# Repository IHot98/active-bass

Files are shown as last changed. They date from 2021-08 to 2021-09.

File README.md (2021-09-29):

# Aktivna bass gitara s ugrađenim zvučnikom

Dizajn tiskane pločice napravljem pomoću KiCad-a.

Tiskana pločica dizajnirana je kao jednoslojna pločica radi lakšeg procesa jetkanja, a komponente su dijelom THT i SMD jer u trenutku izrade nije bilo pristupa drugačijim.

## Slike

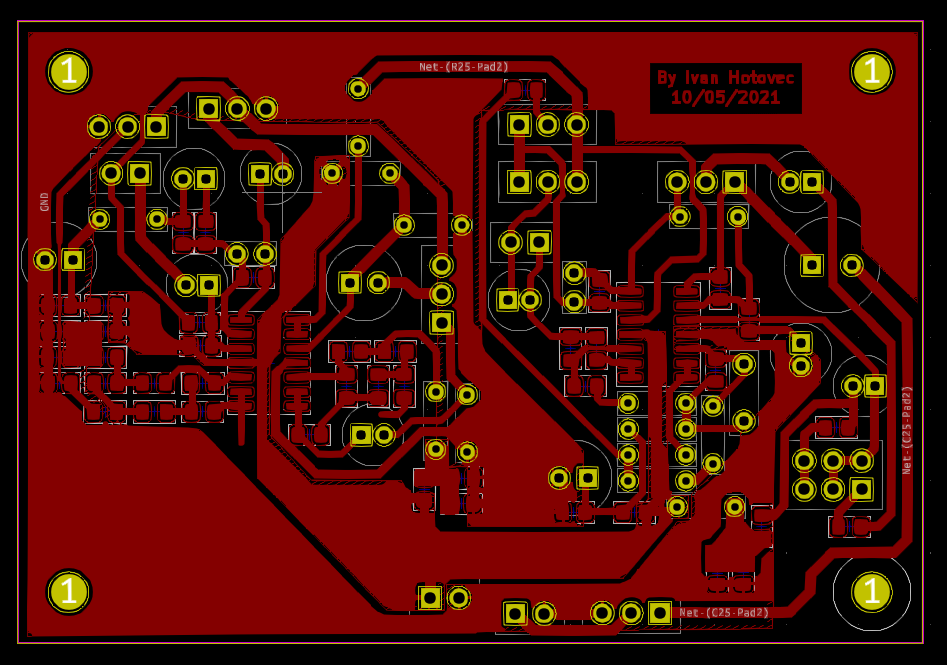
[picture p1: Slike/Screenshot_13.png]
Layer 1


Prikaz dizajna pločice

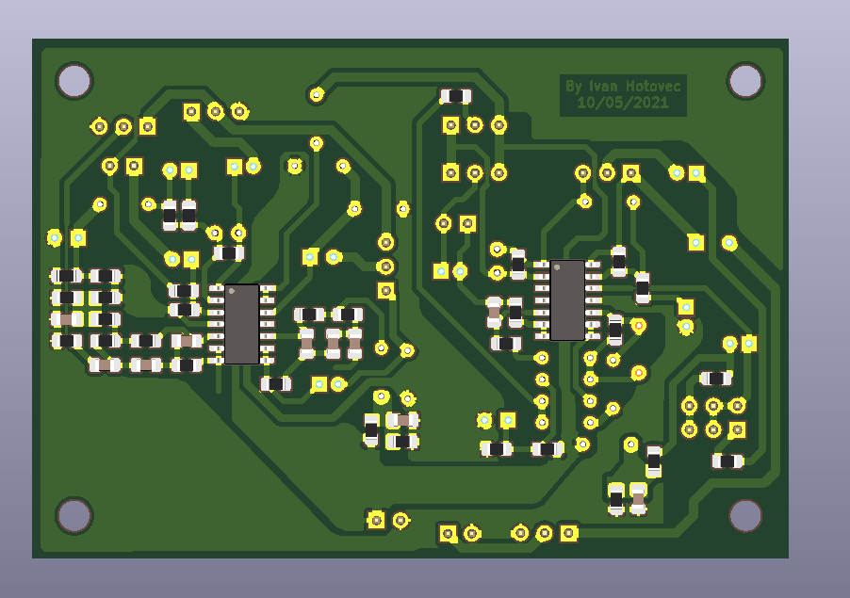
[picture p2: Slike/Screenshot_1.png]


3D Prikaz

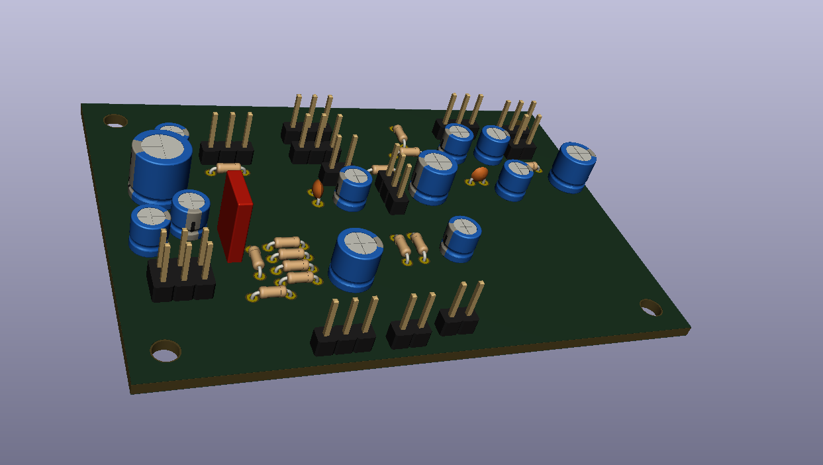
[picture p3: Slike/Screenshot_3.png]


3D Prikaz

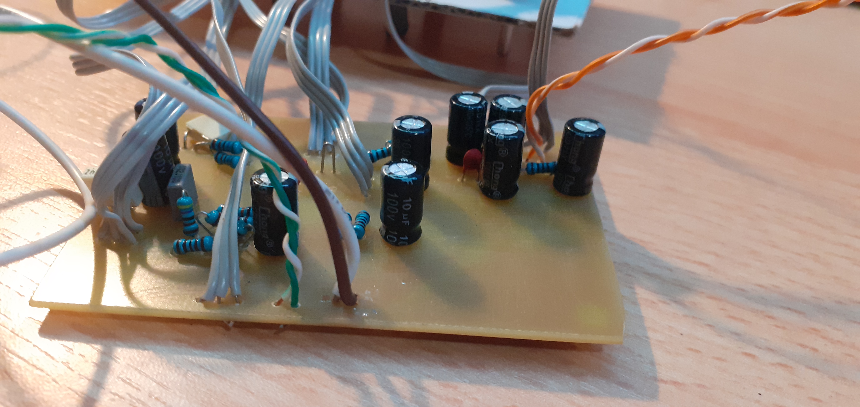
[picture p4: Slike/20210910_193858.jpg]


Izrađeni sklop

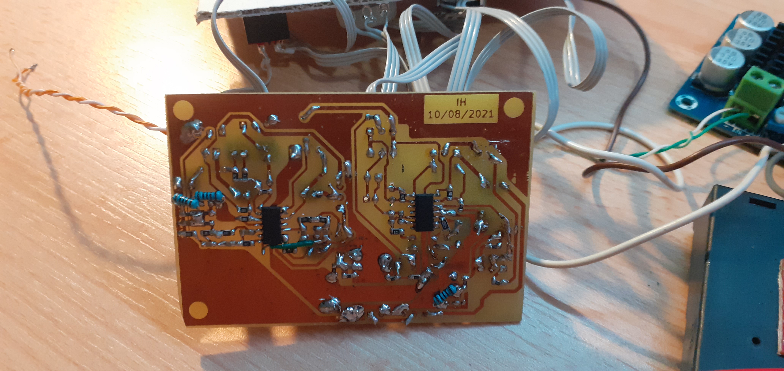
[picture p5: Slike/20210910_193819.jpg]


Izrađeni sklop

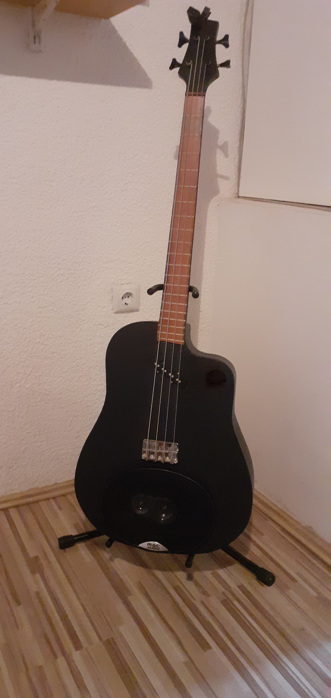
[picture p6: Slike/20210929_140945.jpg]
Kompletirani projekt


Kompletirana bass gitara

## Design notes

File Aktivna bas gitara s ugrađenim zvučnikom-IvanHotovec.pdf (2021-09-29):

SVEUČILIŠTE JOSIPA JURJA STROSSMAYERA U OSIJEKU

FAKULTET ELEKTROTEHNIKE, RAČUNARSTVA I

INFORMACIJSKIH TEHNOLOGIJA

Sveučilišni studij

## AKTIVNA BAS GITARA S UGRAĐENIM ZVUČNIKOM

Završni rad

## Ivan Hotovec

Osijek, 2021.

SADRŽAJ

### 1. UVOD

Prilikom svatovskih pratnji ili sličnih glazbenih nastupa gdje je potrebno biti u pokretu, najčešće

se koristi berda ili kontrabas u sklopu glazbenog sastava. Ti su instrumenti jako veliki, teški i

nezgrapni za nositi te glazbeniku predstavljaju problem u tim situacijama. Ovaj se rad temelji na

rješavanju problema s dizajniranjem i izradom instrumenta koji je manji, lakši za nositi i bez

utjecaja na glasnoću i kvalitetu zvuka.

Problem veličine i mase instrumenta rješava se na način da se tradicionalno bas pojačalo i zvučnik

integriraju u sami instrument te da se napravi takozvani „all-in-one“ instrument.

U radu će se obratiti pozornost na dizajniranje predpojačala, odabir adekvatnog pojačala snage i

sustav baterija kojim će se svi sklopovi napajati.

### 1.1. Zadatak završnog rada

Zadatak završnog rada je izrada i testiranje aktivne bas gitare s ugrađenim zvučnikom.

### 2. PRIKAZ CIJELOG SUSTAVA

Slika 2.1 prikazuje blokovsku shemu cijelog sustava sa svim podsustavima korištenim u ovome

radu.

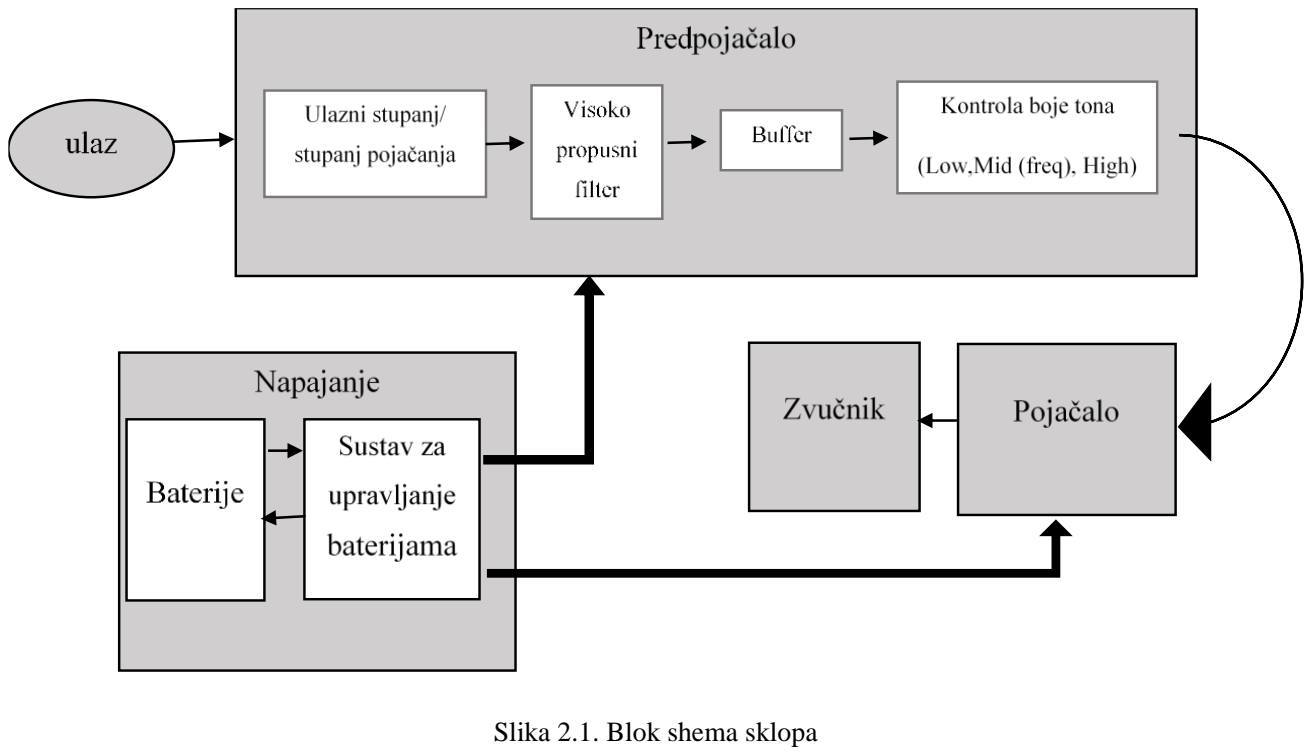
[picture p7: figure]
Slika 2.1. Blok shema sklopa

### 3. PREDPOJAČALO

### 3.1. Ulazni stupanj

Ulazni stupanj izveden je pomoću jednog operacijskog pojačala u neinvertirajućem spoju, a

regulacija pojačanja odvija se pomoću potenciometra spojenog na izlaz operacijskog pojačala.

Korišteno je operacijsko pojačalo TL074. Bitne karakteristike TL074 pojačala su niski šum i

visoka ulazna impedancija zato što koristi JFET-ove kao ulazni stupanj. Ulazni stupanj služi za

naponsko pojačanje za pojačalo, a budući da ima veliki ulazni otpor, na njega se može spojiti

većina izvora signala s visokom ili niskom izlaznom impedancijom. Ulazni stupanj izveden je

pomoću operacijskih pojačala jer je jednostavnije, jeftinije i pouzdanije od izvedbe s diskretnim

tranzistorima.

U dolje navedenoj shemi (Slika 3.1.) kondenzatori C1 i C5 služe za filtriranje DC komponente

signala, a otpornik R7 je u negativnoj povratnoj vezi te s otpornicima R3, R8, određuju pojačanje

ovoga stupnja. Naponsko pojačanje ovoga stupnja može se izračunati po formuli:

Av = 1 + (

R2
R1
) | (3.1.)

Kada se uvrste komponente ovoga sklopa u formulu dobije se formula:

Av = 1 + (

R7
R3 ∗ R8
R3 + R8

+ R6

)
(3.2.)

Av = 1 + (
10k
2.7k ∗ 1.8k
2.7k + 1.8k

+ 1k

) = 5.807 = 15.27dB | (3.3.)

Dizajnom ovoga sklopa dobiva se naponsko pojačanje od +15dB.

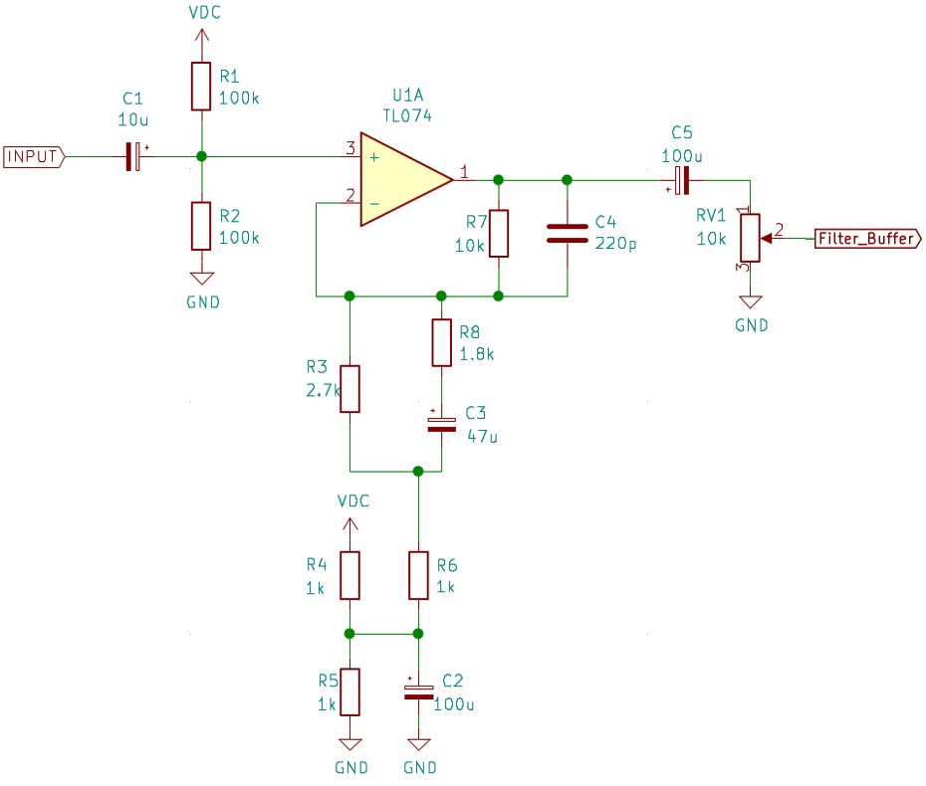
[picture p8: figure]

### 3.2. Kontrola boje tona

### 3.2.1. Bass i treble

Primarne kontrole boje tona kao i uvijek su bas i treble, odnosno kontrola niskih i visokih tonova.

Postoji mnogo različitih načina na koje se mogu provesti kontrole varijabilne frekvencije, ali ova

je metoda prilično jednostavna i dovoljno dobro funkcionira za potrebe ovoga sklopa. Kontrola

boje niskih i visokih tonova bazirana je na principu Wien-ovog mosta. Kontrola boje tona niskih i

visokih ima prilagodljivu frekvenciju pojačanja ili prigušenja. Niski tonovi mogu se regulirati od

100Hz do 500Hz, a visoki od 400Hz do 1.7kHz. Sklop omogućuje pojačanje (+12dB) i prigušenje

(-12dB) na obje kontrole tona. Kontrola niskih koristi giratorski baziranu zavojnicu, a kontrola

visokih koristi prilagodljiv multiplikator kapaciteta.

Slika 3.1. Shema ulaznog stupnja predpojačala

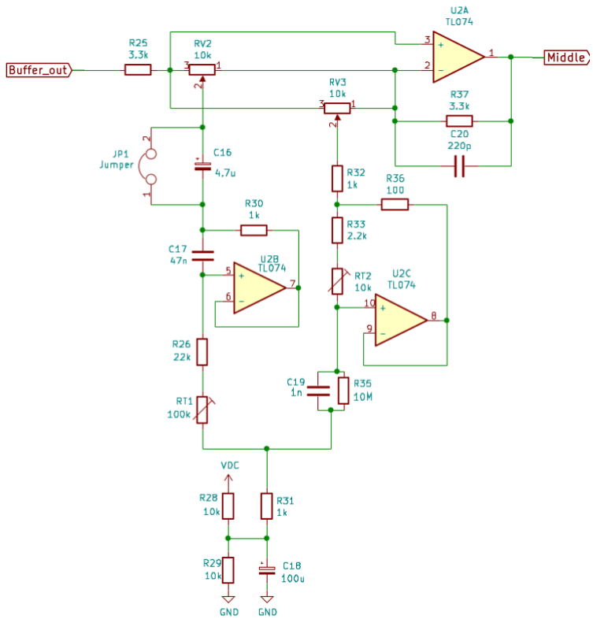
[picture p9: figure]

Slika. 3.2. Električna shema sklopa za kontrolu boje tona niskih i visokih frekvencija

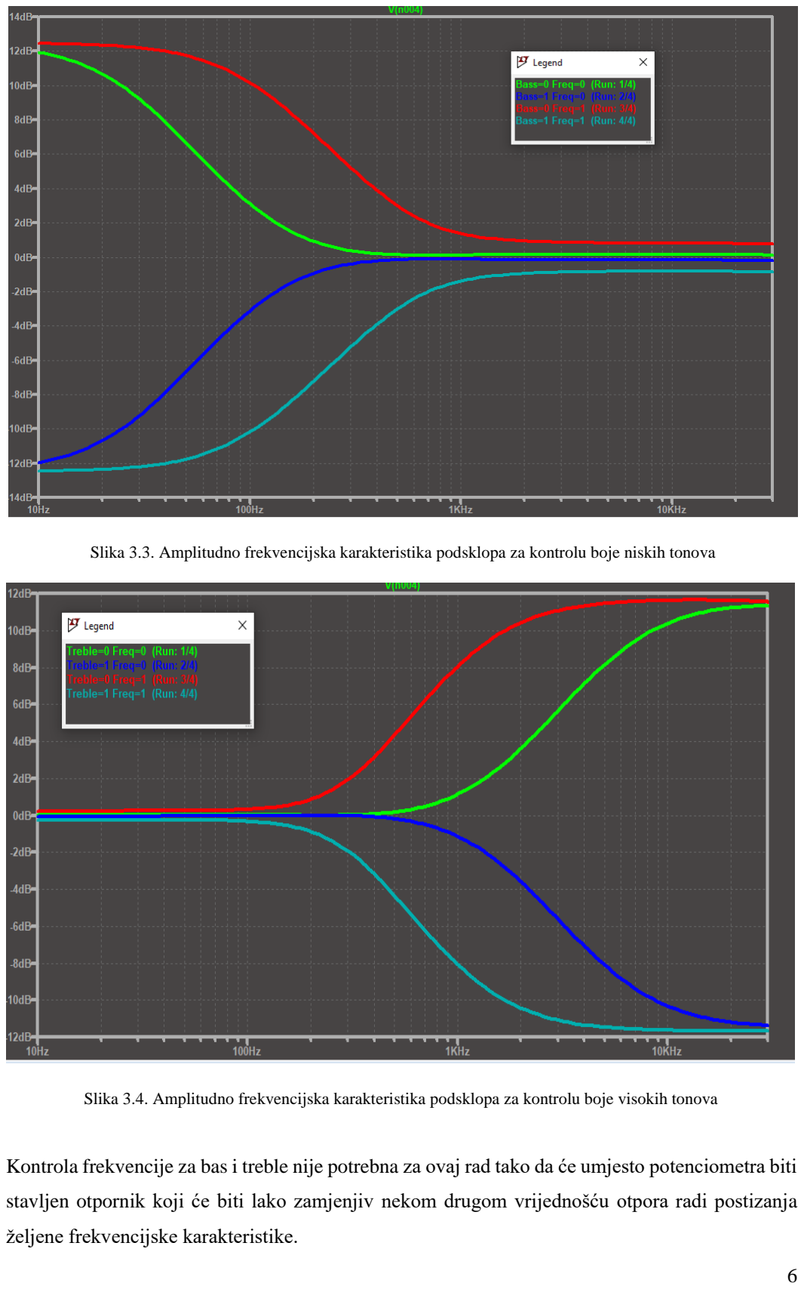
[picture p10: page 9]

Kontrola frekvencije za bas i treble nije potrebna za ovaj rad tako da će umjesto potenciometra biti

stavljen otpornik koji će biti lako zamjenjiv nekom drugom vrijednošću otpora radi postizanja

željene frekvencijske karakteristike.

Slika 3.3. Amplitudno frekvencijska karakteristika podsklopa za kontrolu boje niskih tonova

Slika 3.4. Amplitudno frekvencijska karakteristika podsklopa za kontrolu boje visokih tonova

### 3.2.2. Middle – kontrola boje srednjih tonova

Middle kontrola napravljena je tako da ima pojačanje i prigušenje od maksimalno 12dB. Spaja se

kaskadno poslije kontrole niskih i visokih tonova (basi treble). Frekvencija pojačanja ili prigušenja

može se prilagođavati duplim potenciometrom od 650Hz do 7.7kHz. Frekvencijsko se područje

može dodatno promijeniti tako da mijenjamo vrijednosti kondenzatora C21 i C23, ali treba

pripaziti da su kondenzatori jednakih vrijednosti. Koristeći formulu (3.4.) za RC frekvenciju može

se izračunati koje kondenzatore treba uzeti za određeni raspon frekvencija.

f =

1
2πRC

(3.4)

U ovome sklopu Q faktor ostaje konstantan kako se mijenja frekvencija, a zbog minimizacije šuma

u sklopu korišteni su otpori relativno niskih otpornosti.

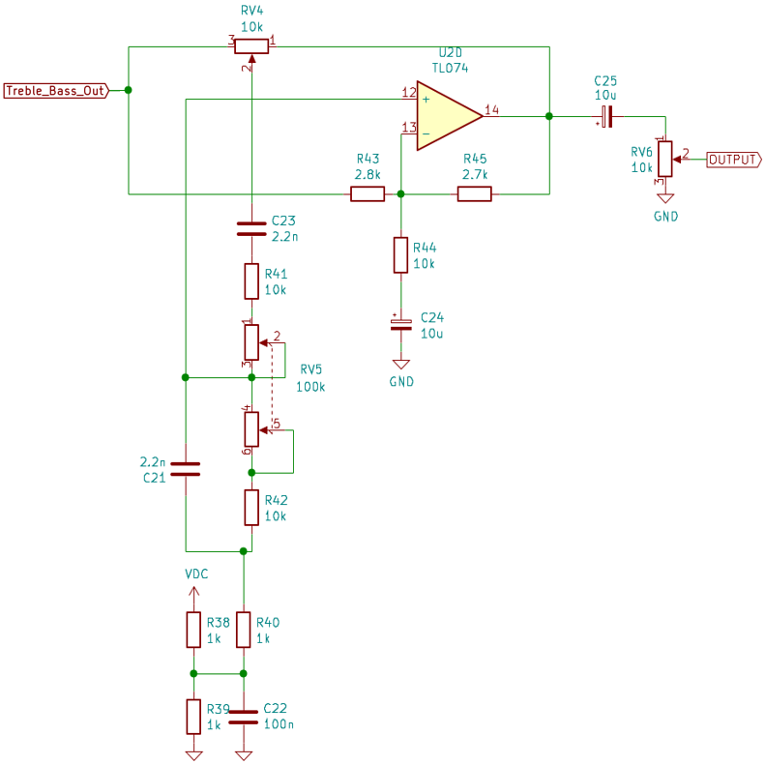
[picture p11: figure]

Slika 3.5. Električna shema sklopa za kontrolu boje srednjih tonova

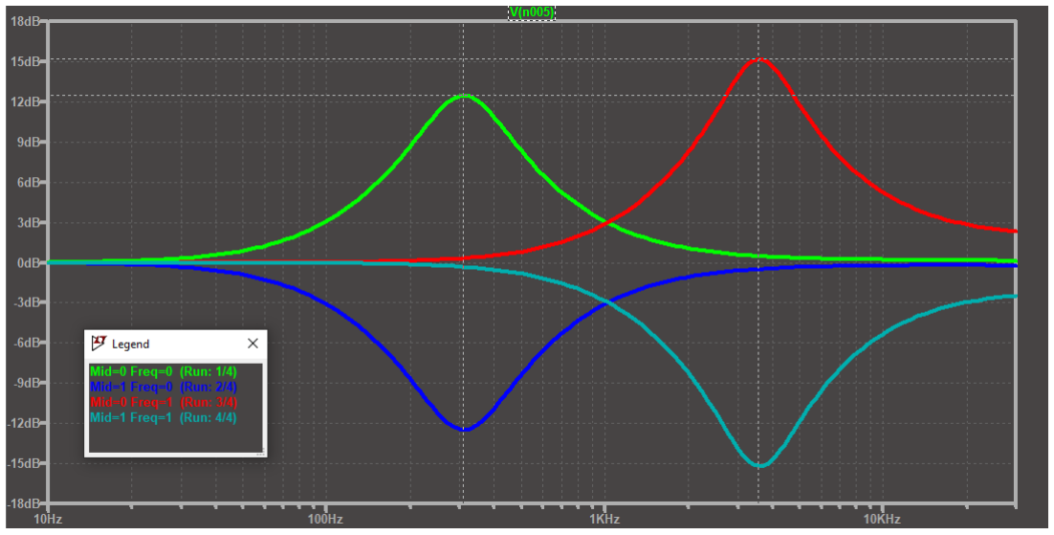
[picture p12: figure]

Na slikama 3.3, 3.4 i 3.6 možemo primijetiti prozor s natpisom legenda u kojemu različitim bojama

ima napisano Bass, Treble ili Mid i Freq te je izjednačeno s 1 ili 0. Navedeni natpisi predstavljaju

varijablu koja služi za određivanje položaja klizača na potenciometru u simulaciji. Nula

predstavlja da je klizač potenciometra na krajnjem minimalnom položaju, dok jedinica predstavlja

krajnji maksimalni položaj. Vrijednost varijable položaja klizača može biti bilo koji realni broj od

0 do 1, ali radi preglednosti grafova u simulaciji uzeti su samo krajnji položaji klizača. Varijable

označene s Bass, Treble i Mid utječu na pojačanje i prigušenje toga dijela sklopa, a varijabla Freq

utječe na frekvenciju gdje će to pojačanje ili prigušenje biti.

### 3.2.1. Wien-ov most

Wien-ov most srce je gotovo svih audio oscilatora (Slika 3.7.). U oscilatoru, krug pojačanja se

koristi za dobivanje pozitivne povratne veze oko wien-ovog mosta, a negativna povratna veza

zahtijeva stabilizaciju pojačanja kako bi se dobilo pojačanje od 3, što je dovoljno za održavanje

oscilacije. Kada se wien-ov most kombinira s povratnom vezom, Q faktor je uvelike poboljšan, a

gubitak snage više nije problem. Pod uvjetom da je pojačanje sklopa ispod 3, wien-ov most neće

iznenada postati oscilator, a u sklopu prikazanom na slici 3.8. će pružiti +/- 9dB pojačanja i

prigušenja, pod kontrolom potenciometra. Kako bi sklop bio korisniji, sklop mora imati i

mogućnost mijenjanja frekvencije. To se postiže pomoću dvostrukog potenciometra tako da se oba

otporna dijela mosta mogu mijenjati. Frekvencija se može podesiti u rasponu od jedne dekade, što

je nešto više od tri oktave. Ako je potrebno više pojačanja i prigušenja (i malo veći Q), može se

staviti C1 dvostruko veći od C2 (ili dodati R5 – slika 3.8.). Promjenom C1 znači da će se

Slika 3.6. Amplitudno frekvencijska karakteristika sklopa za kontrolu boje srednjih tonova frekvencija također promijeniti, a kako bismo mogli izračunati frekvenciju možemo koristiti

formulu (3.5.).

f =

0.717
2πRC

(3.5.)

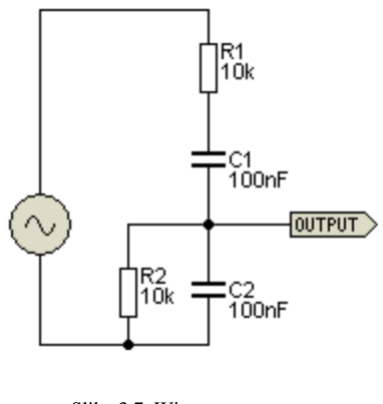
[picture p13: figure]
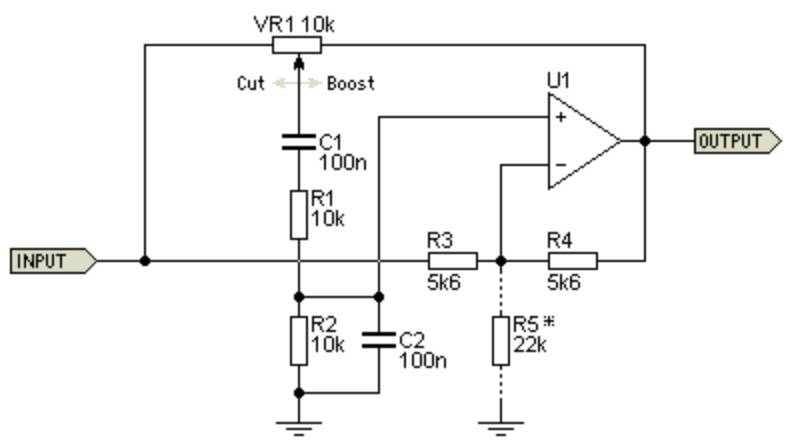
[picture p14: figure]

### 3.2.2. Giratorski filter

Giratori ili simulirane zavojnice neizmjerno su korisni elektronički građevni blokovi. U

jednostavnim terminima, girator je aktivni pretvornik impedancije. Korištenjem kondenzatora kao

reaktivne komponente, girator pretvara impedanciju s kapacitivne na induktivnu. Umjesto

korištenja zavojnice koja je namotana oko magnetske jezgre, aktivni uređaj, najčešće operacijsko

pojačalo, koristi se kao pretvornik impedancije. Na taj se način kondenzator može koristiti kao

Slika 3.7. Wien-ov most

Slika 3.8. Wien-ov most u shemi s operacijskim pojačalom kontrolni element, a operacijsko pojačalo transformira njegovu impedanciju tako da se cijeli krug

ponaša kao zavojnica. U stvarnosti, zavojnica će imati značajnu otpornost namota i jer je to namot

žice s feromagnetnom jezgrom, jezgra će pokupiti zračenja magnetskog polja. Osim toga, postoji

i kapacitet unutar namota, što znači da će imati samo rezonantnu frekvenciju koja može biti čak i

unutar audio spektra. Usporedbom, zavojnica ostvarena s operacijskim pojačalom i nekoliko

pasivnih komponenata gotovo da neće imati samostalnog kapaciteta i može biti dizajnirana tako

da ima iznimno nizak otpor namota. Također nema ničega što bi moglo pokupiti zalutala

magnetska polja, pa postavljanje na tiskanoj pločici nije kritično. Giratori se ne moraju nositi s

gubicima jezgre i osjetljivosti na magnetska polja. S obzirom na to da je jeftin, a može se

podešavati i štedi na prostoru, čini se kao vrlo dobar izbor za korištenje u sklopovima za kontrolu

boje tona.

3.3. 40 Hz visoko propusni filter

Visoko-propusni filter izveden je poput uobičajenog Sallen-Key filtera, ali uz neka

pojednostavljenja kako bi se smanjio broj različitih vrijednosti komponenata. Q faktor ili faktor

dobrote optimiziran je na način da omogućuje veću ulaznu impedanciju nego što bi inače bilo

moguće, s tim da je konačni Q ta dva filtera spojenih kaskadno iznosi točno 0.707, nema pojačanja

na donjoj graničnoj frekvenciji, poput tradicionalnog butterworth-ovog filtera

Sklop filtera može se zaobići korištenjem DPDT prekidača kao što je vidljivo na shemi te isti

omogućuje da filter bude uključen kada postoji potreba za uklanjanjem neželjenih niskih

frekvencija.

Kako ne bi dolazilo do pucketanja zvuka pri uklapanju i isklapanju sklopke, postavljeni su

otpornici R9 i R22 i kondenzator C14. Pucketanje u zvuku obično se dešava kada postoji razlika

u potencijalu između kontakata prekidača ili ako postoji kondenzator kojemu će jedan izvod biti

„u zraku“ što ovi otpornici i kondenzator sprječavaju.

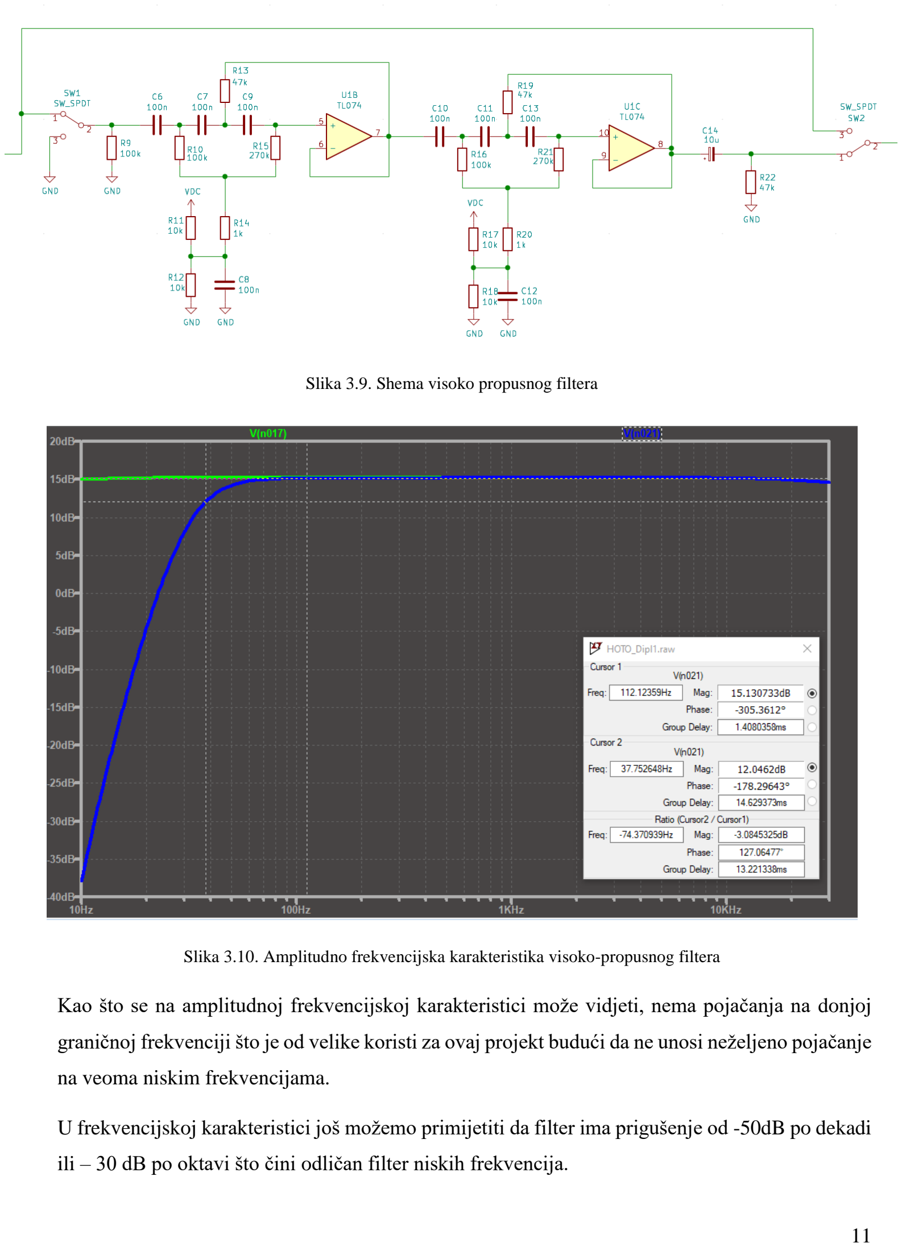
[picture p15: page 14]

Kao što se na amplitudnoj frekvencijskoj karakteristici može vidjeti, nema pojačanja na donjoj

graničnoj frekvenciji što je od velike koristi za ovaj projekt budući da ne unosi neželjeno pojačanje

na veoma niskim frekvencijama.

U frekvencijskoj karakteristici još možemo primijetiti da filter ima prigušenje od -50dB po dekadi

ili – 30 dB po oktavi što čini odličan filter niskih frekvencija.

Slika 3.9. Shema visoko propusnog filtera

Slika 3.10. Amplitudno frekvencijska karakteristika visoko-propusnog filtera

Frekvencija reza prilagođena je na 40hz specifično zbog toga što najniži ton na bas gitari iznosi

41 Hz, te kako ne bismo prigušavali „korisne“ tonove rez filtera mora biti manji od najnižega tona

što instrument može reproducirati.

### 3.4. Postavljanje radne točke

Kako u ovome dizajnu koristimo operacijska pojačala, a za rad operacijskog pojačala potreban je

i pozitivan i negativan napon, a budući da se sklop napaja pomoću baterija, nije moguće dobiti

dualni (+/-) napon na kojima OP može raditi nego je potrebno napraviti stabilnu referentnu točku

na pola napona što nam je omogućeno od baterija. To postižemo sklopom na slici 3.11. gdje R4 i

R5 služe kao naponsko dijelilo, a R6 i C2 kao filter radi stabilnosti referentne točke i neovisnost

od napajanog dijela sklopa.

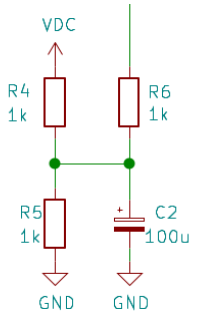
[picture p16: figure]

Kod odabira otpornika za ovaj sklop potrebno je imati na umu otpornost tereta tj. otpornici R4 i

R5 moraju biti deset puta manji nego otpor tereta te kolika struja prolazi kroz te otpore kako bi se

mogli odabrati dovoljno snažni otpornici.

Slika 3.11. Sklop za postavljanje radne točke

### 3.5. Izrada tiskane pločice

### 3.5.1. Dizajn tiskane pločice

Dizajn tiskane pločice napravljen je u KiCad programskom sučelju koji je brz i jednostavan za

korištenje pri izradi manjih i jednostavnijih tiskanih pločica. Tiskana pločica dizajnirana je kao

jednoslojna pločica s kombinacijom SMD i THT komponenata radi lakšeg razvijanja pločice.

Na slici 3.12. može se vidjeti gotov dizajn tiskane pločice.

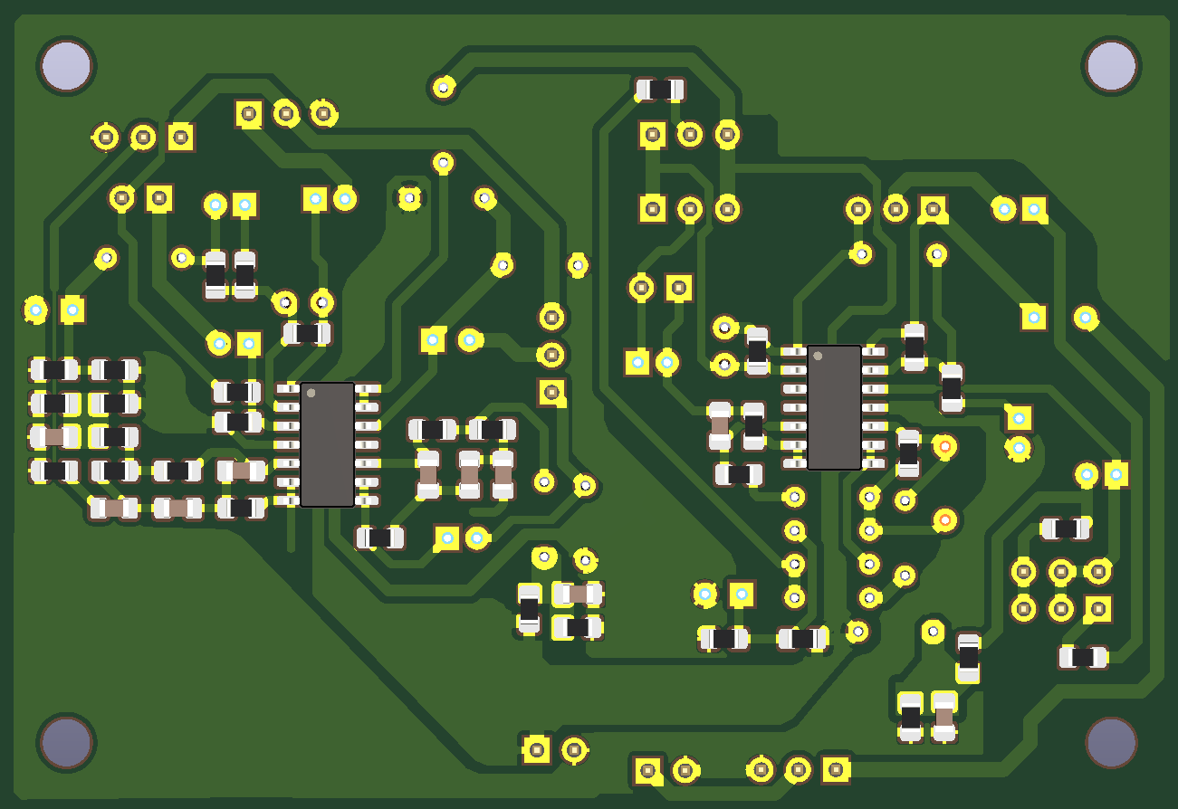
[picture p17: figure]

### 3.5.2. Jetkanje tiskane pločice

Za razvijanje pločice korišten je foto postupak gdje se dizajn pločice ispiše na paus papir s

laserskim printerom. Za foto postupak trebaju posebne pločice s tankim slojem fotorezista, sloj

koji kada se izloži svjetlosti gubi otpornost na otapala, te se paus papir prisloni na bakrenu stranu

pločice i zatim osvijetli s UV svjetlom. Nakon osvjetljivanja pločicu stavimo u otopinu natrijevog

hidroksida gdje se odstrani fotorezist, zatim stavimo pločicu u otopinu solne kiseline i vodikovog

peroksida gdje se nagriza bakar. Nakon nagrizanja bakra na tiskanoj pločici izbuše se rupe za

komponente s žičanim izvodima. Tiskane pločice su izrađene u kombinaciji tehnologije površinske

Slika 3.12. Tiskana pločica montaže (SMD) i komponentama s žičanim izvodima (Trough-hole). Bitne prednosti tehnologije

površinske montaže komponenata su minijaturizacija tj. ušteda na prostoru i masi, bolje električke

karakteristike, bolje mehaničke karakteristike, odnosno veća izdržljivost na udarce i vibracije.

Jedini nedostatci tehnologije površinske montaže su složeniji tehnološki postupci lemljenja, teže

ispitivanje zbog slabije pristupačnosti priključcima na komponenti i nedostupnost nekih

komponenti u SMD-u.

### 3.6. Testiranje

Nakon izrade tiskane pločice i lemljenja svih komponenti, potrebno je provjeriti ispravnost/točnost

izrade. To se postiže testiranjem koje se odvija pomoću ARTA softvera i zvučne kartice gdje se

promatra frekvencijski odaziv sklopa.

Kako bi se dobili točni rezultati, potrebno je kalibrirati zvučnu karticu programom. To se čini

postupkom opisanom u korisničkom priručniku koji se može naći na službenoj web stranici.

Kako bi se zvučna kartica zaštitila od višeg napona nego što je to predviđeno, potrebno je prigušiti

signal. To se radi dodavanjem sklopa prije ulaza u zvučnu karticu kao što je na slici 3.13.

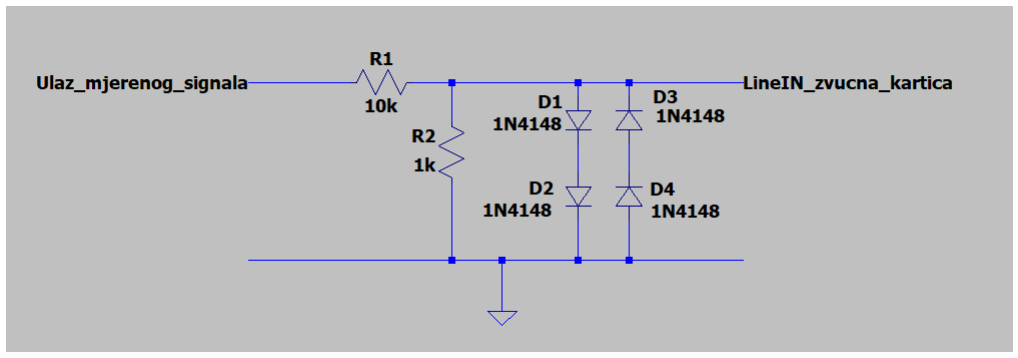
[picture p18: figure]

Slika 3.13. sklop za prigušenje signala

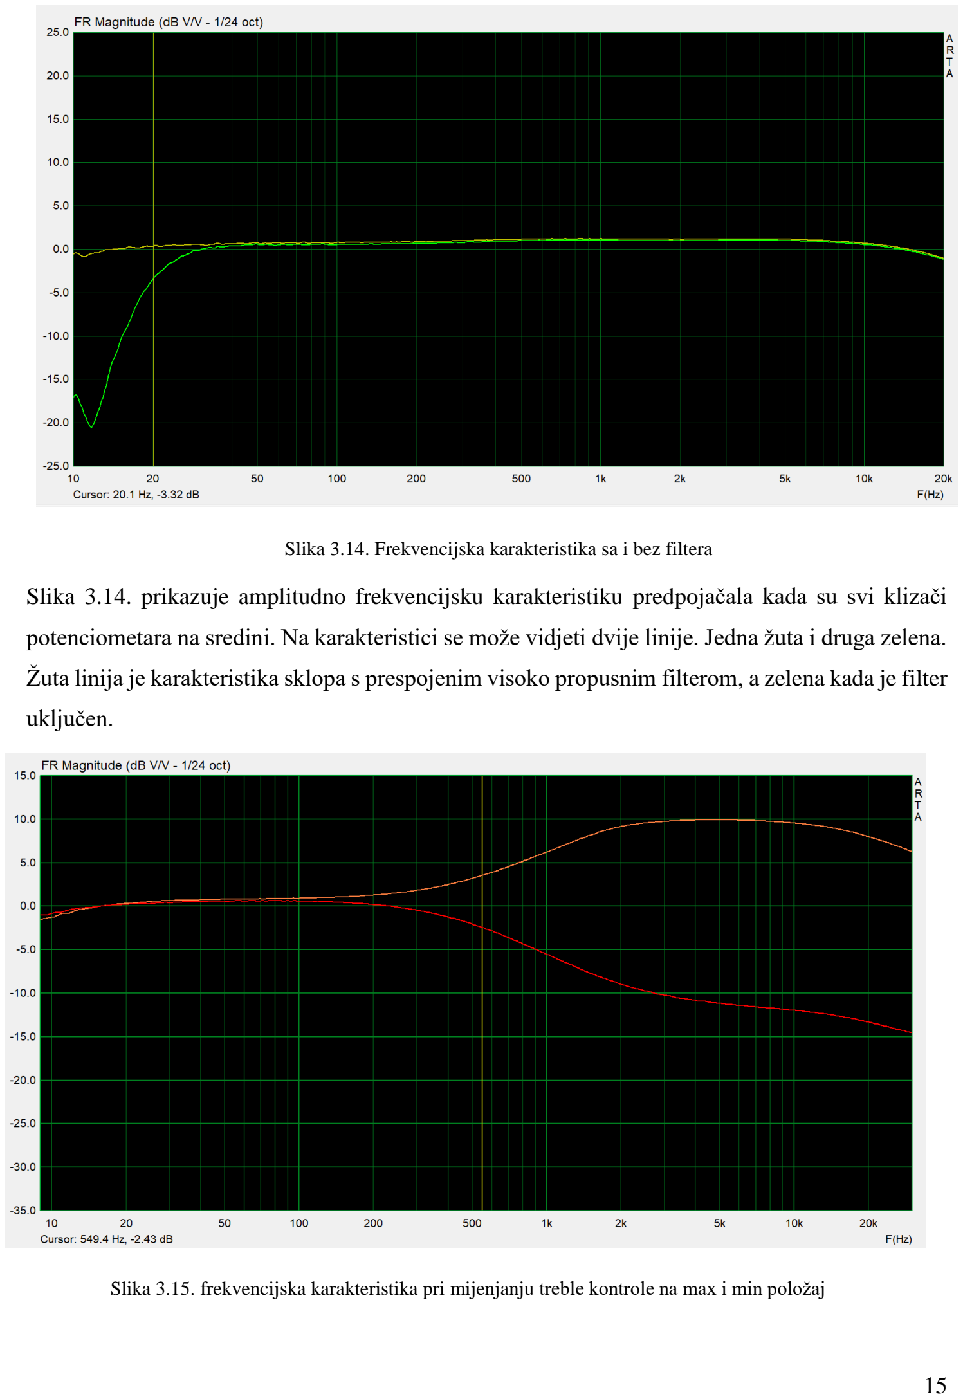
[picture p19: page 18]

Slika 3.14. prikazuje amplitudno frekvencijsku karakteristiku predpojačala kada su svi klizači

potenciometara na sredini. Na karakteristici se može vidjeti dvije linije. Jedna žuta i druga zelena. Žuta linija je karakteristika sklopa s prespojenim visoko propusnim filterom, a zelena kada je filter

uključen.

Slika 3.14. Frekvencijska karakteristika sa i bez filtera

Slika 3.15. frekvencijska karakteristika pri mijenjanju treble kontrole na max i min položaj

Slika 3.15 prikazuje amplitudno frekvencijsku karakteristiku kada su svi klizači potenciometara

na sredini osim potenciometra za kontrolu visokih tonova (Treble). Crvenom je linijom prikazana

karakteristika kada je klizač Treble potenciometra na minimumu (potpuno zarotiran u lijevo), a

narančastom kada je klizač na maksimumu (potpuno zarotiran u desno).

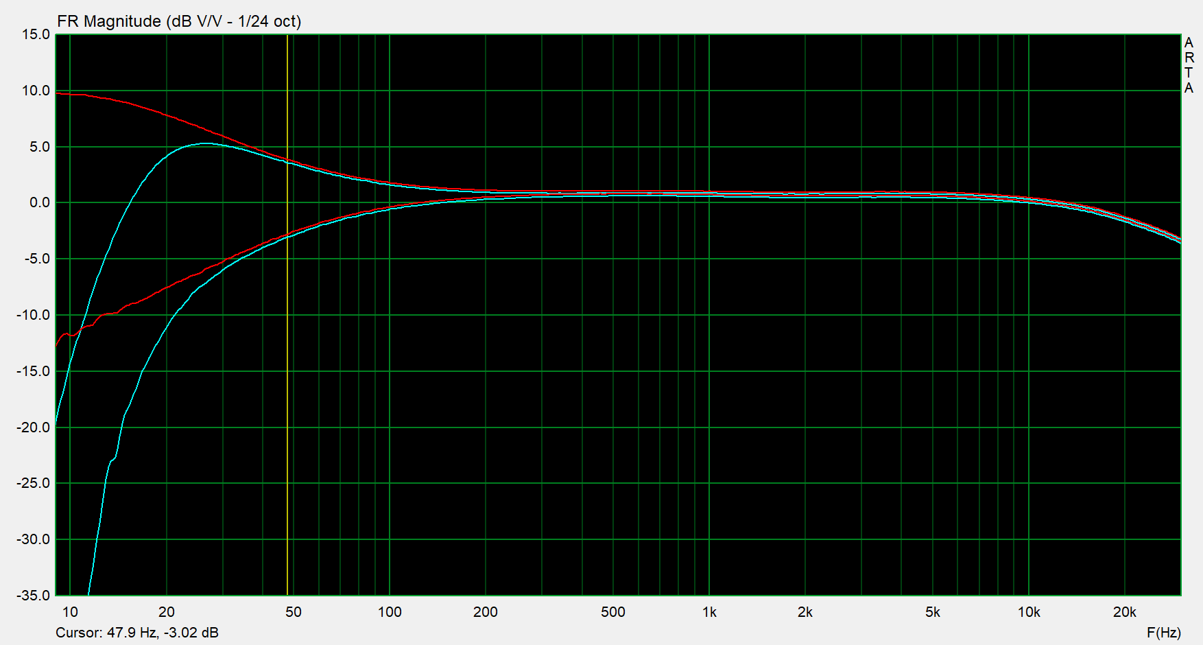
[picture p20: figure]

Slika 3.16 prikazuje amplitudno frekvencijsku karakteristiku kada su svi klizači potenciometara

na sredini osim potenciometra za kontrolu niskih tonova (Bass). Crvenom je linijom prikazana

karakteristika bez uključenog visoko-propusnog filtera, a plava s uključenim visoko propusnim

filterom.

Slika 3.16. frekvencijski odaziv bass kontrole tona s i bez filtera

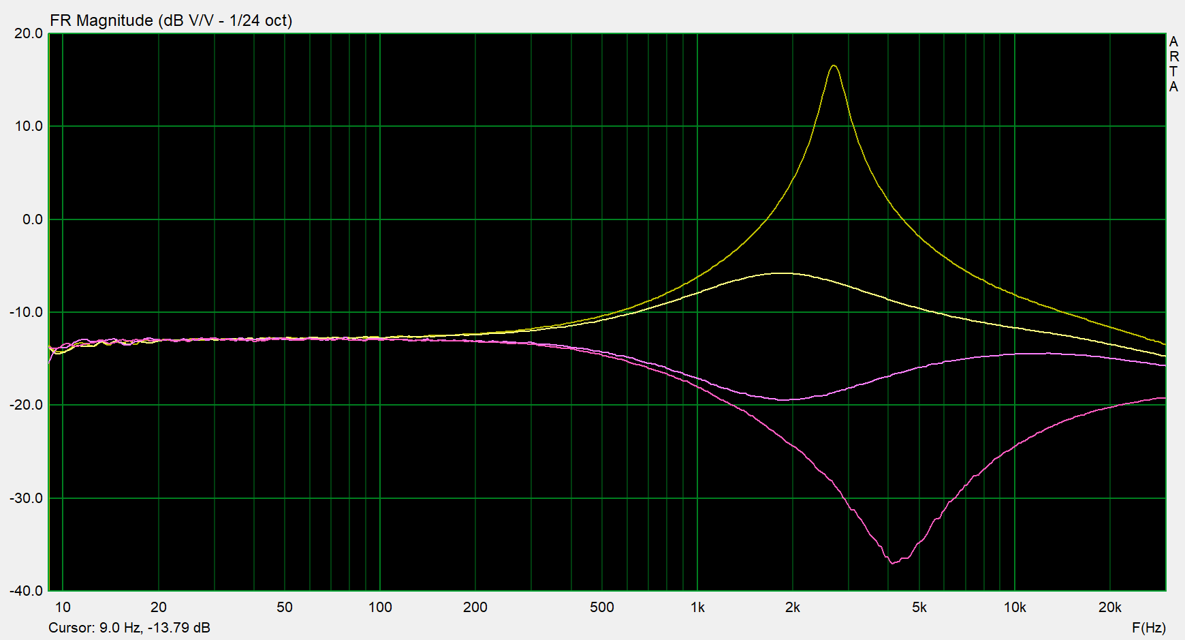
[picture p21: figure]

Slika 3.17 prikazuje amplitudno frekvencijsku karakteristiku kada su svi klizači potenciometara

na sredini osim potenciometra za kontrolu srednjih tonova (Mid) i potenciometra za kontrolu

frekvencije. Svijetlo-žutom linijom prikazana je karakteristika kada je Mid potenciometar

zarotiran krajnje u desno i kada je potenciometar za frekvenciju zarotiran krajnje u lijevo. Tamno-

žutom linijom prikazana je karakteristika kada je Mid potenciometar zarotiran u potpunosti u

desno i kada je potenciometar za frekvenciju zarotiran u potpunosti u desno. Ljubičastom linijom

je prikazana karakteristika kada je Mid potenciometar zarotiran u potpunosti u lijevo i kada je

potenciometar za frekvenciju zarotiran skroz u lijevo. Ružičastom linijom prikazana je

karakteristika kada je Mid potenciometar zarotiran u potpunosti u lijevo i kada je potenciometar

za frekvenciju zarotiran u potpunosti u desno.

Mjerenje se izvršilo na način da se na izlaz zvučne kartice puštao sinusoidni signal od 10 Hz do

50kHz pri frekvenciji uzorkovanja od 192kHz te se na ulaz zvučne kartice spojio izlaz sklopa i

mjerila se amplituda sinusa na svakoj frekvenciji.

Slika 3.17. Frekvencijski odaziv kontrole srednjih tonova

### 4. POJAČALO

### 4.1. Odabir klase pojačala

Postoji više klasa audio pojačala i svake od njih imaju svoje dobre i loše strane. Za potrebe ovoga

rada pojačalo treba biti što efikasnije i što manje mase te je potrebno da samo pojačalo može raditi

s jednom naponskom razinom tj. da pojačalo može raditi s jednostrukim napajanjem („single

rail“) odnosno direktno sa baterija. Kada uzmemo u obzir ove kriterije jedino D klasa pojačala

zadovoljava sve uvjete. Točnije čip pojačalo TPA3116D2 u PBTL (eng. Parallel Bridge Tied

Load) modu, odnosno dva kanala spojeno u paralelni mostni spoj.

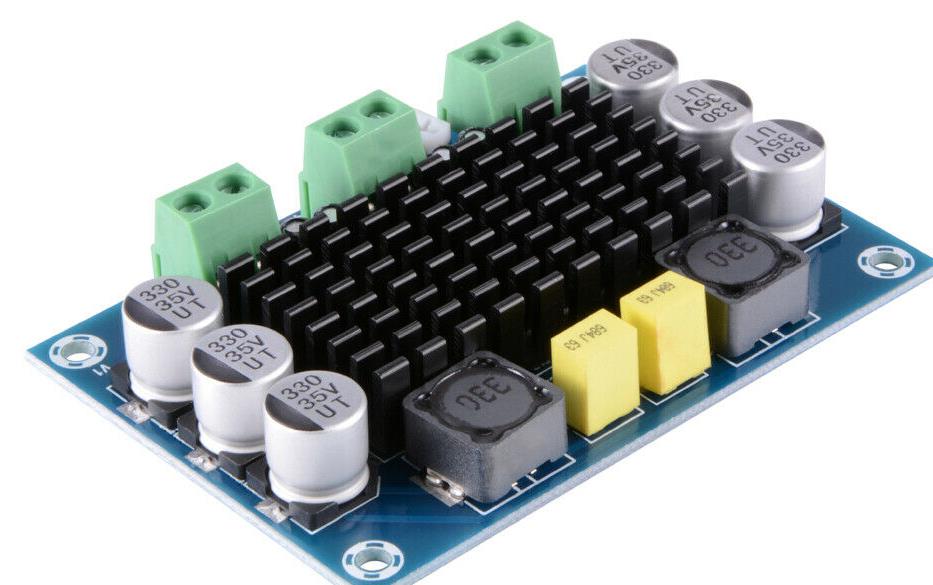
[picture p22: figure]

### 4.2. Specifikacije pojačala

Izabrano pojačalo radi na naponima od 12 do 26V, te na naponu od 24V može podnijeti

maksimalnu snagu od 100W što je i više nego dovoljno za naše potrebe. Nadalje pojačalo ima

visoki SNR (100dB) što omogućava iznimnu kvalitetu zvuka. Samo pojačalo ima vrlo male

dimenzije (79x54x16mm) i masu (54g).

Čip TPA3316D2 pruža sveobuhvatnu zaštitu od kratkog spoja, prekomjerne temperature,

prenapona, pod napona i istosmjernih smetnji i preopterećenja.

Slika 4.1. TPA3116D2 pojačalo

### 5. BATERIJE / BMS

### 5.1. Odabir baterija

Postoje različite vrste baterija napravljene od različitih materijala, a bitna karakteristika za ovaj

rad je da su baterije punjive, da zauzimaju malo prostora, te da su lagane. Neke od poznatijih vrsta

baterija su olovna baterija, litij-polimerska baterija i litij-ionska baterija.

Proučavanjem baterija i njihovih cijena odabiru se litij-ionske baterije u 18650 veličini ćelije.

Svaka ćelija ima maksimalan napon od 4.1V i kada spojimo 4 ćelije u seriju dobivamo adekvatnu

snagu i napon pakiranja baterija.

### 5.2. Sustav za upravljanje baterijama

Budući da se koristi više ćelija baterija u pakiranju nužno je imati nekakvu kontrolu nad njima radi

sigurnosti i dugovječnosti samih ćelija. To možemo postići korištenjem BMS-a odnosno sustava

za upravljanje baterijama.

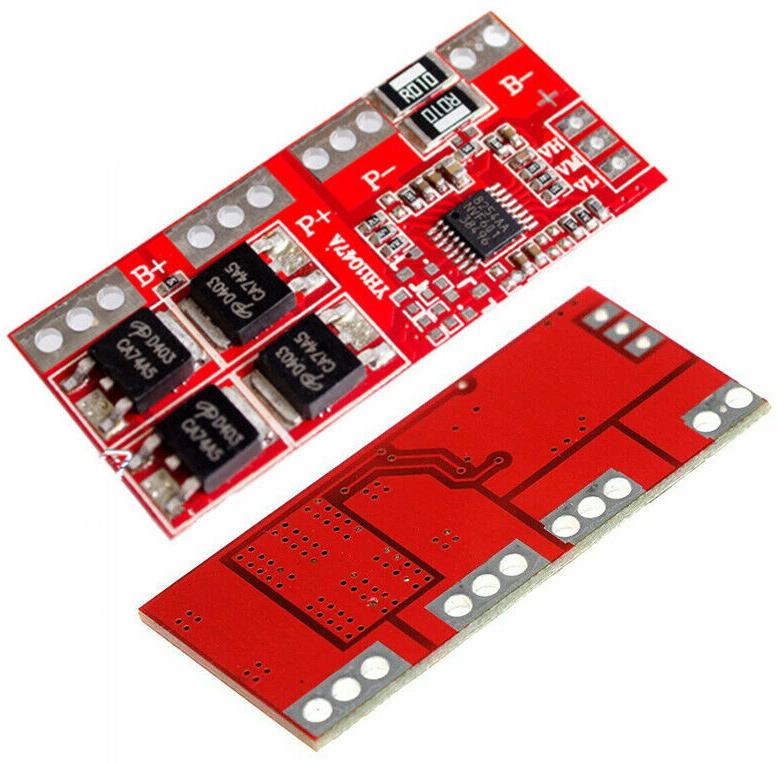
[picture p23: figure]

Ovaj BMS omogućava zaštitu od kratkog spoja, prekomjernog pražnjenja baterija, prekomjernog

punjenja i prekomjerne izlazne struje.

Slika 5.1. Gotova izvedba sustava za upravljanje baterijama

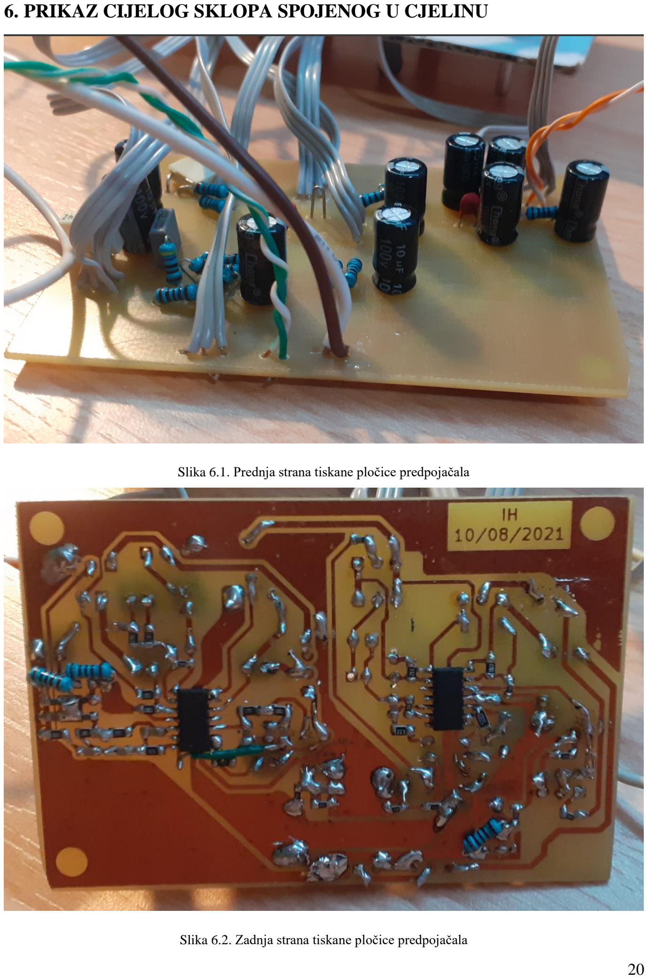
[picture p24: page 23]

### 6. PRIKAZ CIJELOG SKLOPA SPOJENOG U CJELINU

Slika 6.1. Prednja strana tiskane pločice predpojačala

Slika 6.2. Zadnja strana tiskane pločice predpojačala

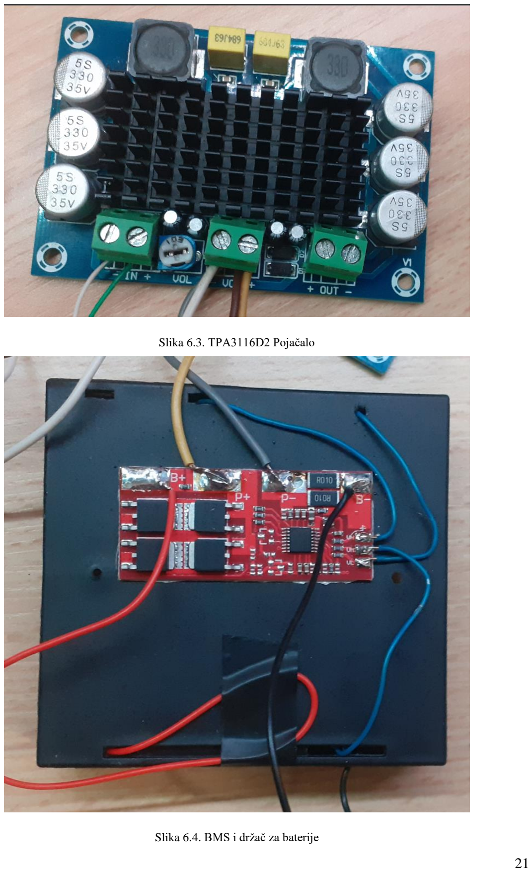
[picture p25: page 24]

Slika 6.3. TPA3116D2 Pojačalo

Slika 6.4. BMS i držač za baterije

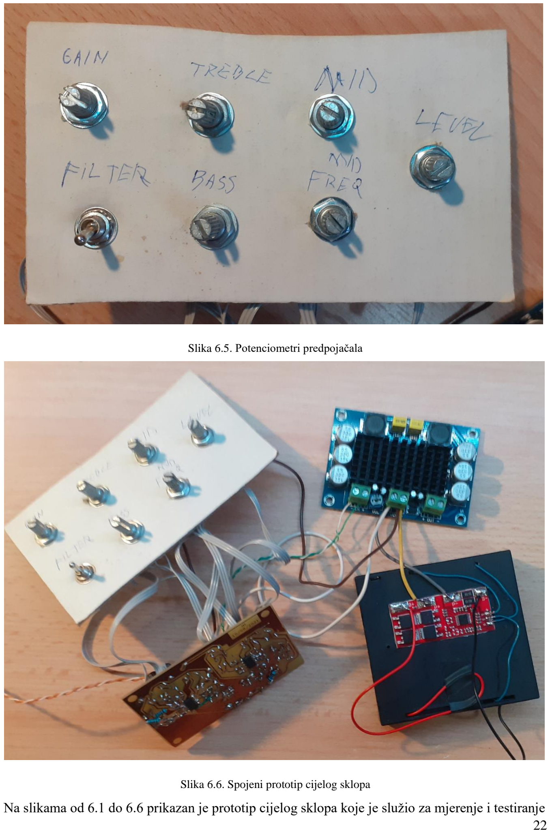
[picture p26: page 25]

Na slikama od 6.1 do 6.6 prikazan je prototip cijelog sklopa koje je služio za mjerenje i testiranje

Slika 6.5. Potenciometri predpojačala

Slika 6.6. Spojeni prototip cijelog sklopa

### 7. ZAKLJUČAK

Izrađeno predpojačalo zbog, velike kontrole boje tona je prigodno za većinu žanrova glazbe, a

budući da ima veliki ulazni otpor na njega se može spojiti bilo kakav pickup, bio to aktivni, pasivni

ili možda piezo pickup, što omogućava razne kombinacije mogućih zvukova.

U kombinaciji s pojačalom i baterijama te adekvatno napravljenim konstrukcijom bass-a, ova bass

gitara pruža ugodnost u sviranju bez kompromisa na kvalitetu i glasnoću zvuka uz mogućnost

pokretnosti.

LITERATURA

[1] Rod Elliott (ESP), Subsonic Filter for Phono preamps, Sub-Woofers, PA Systems, Etc URL: https://sound-au.com/project99.htm
[2] Rod Elliott (ESP), Bass Guitar Amplifier, URL: https://sound-au.com/project152-1.htm
[3] Rod Elliott (ESP), Active Filters Using Gyrators - Characteristics, and Examples, URL: https://sound-au.com/articles/gyrator-filters.htm
[4] Analog Devices, LTspice, URL: https://www.analog.com/en/design-center/design-tools-and-calculators/ltspice-simulator.html (https://www.analog.com/en/design-center/design-tools-and-calculators/ltspice-simulator.html)
[5] KiCad, URL: https://www.kicad.org/
[6] ARTA Software, URL: https://artalabs.hr/

SAŽETAK

U završnom radu opisani su rezultati dizajniranja, izrade i testiranja predpojačala za aktivnu bass

gitaru s ugrađenim zvučnikom. Uz opis dizajna predpojačala, opisan je i odabir adekvatne klase

pojačala snage i adekvatne vrste baterija koje mogu napajati cijeli sustav. Za predpojačalo je bilo

potrebno dizajnirati i izraditi tiskanu pločicu te je taj proces također opisan u radu. Na kraju rada

prikazan je prototip sa spojenim svim ključnim dijelovima sklopa.

Ključne riječi: Bass, Gitara, Pojačalo, Predpojačalo, Zvučnik

ABSTRACT

ACTIVE BASS GUITAR WITH A BUILT-IN SPEAKER

This Bachelor's thesis describes the results of designing, making and testing out the preamplifier for

active bass guitar with a built-in speaker. In addition, selection of the appropriate class of power

amplifier and type of batteries that can power the entire system is described. Aforementioned

components were required to design and make a printed circuit board for the preamplifier. The whole

process is further described. At the end of the paper, a prototype with all connected key parts of the

circuit is presented.

Keywords: Amplifier, Bass, Guitar, Preamplifier, Speaker

ŽIVOTOPIS

Ivan Hotovec rođen je 29. kolovoza 1998. godine u Novoj Gradiški. Pohađao je osnovnu školu

Mato Lovrak u Novoj Gradiški. 2014.godine upisuje Elektrotehničku i ekonomsku školu u Novoj

Gradiški gdje kroz van nastavne aktivnosti razvija interes za analognu elektroniku. U srednjoj školi

sudjeluje i osvaja treće mjesto na državnom ekipnom natjecanju iz elektrotehnike i računalstva u

Splitu. 2017. godine upisuje Fakultet elektrotehnike, računarstva i informacijskih tehnologija u

Osijeku, smjer Elektrotehnika i informacijska tehnologija

Potpis autora:

________________________

PRILOG

P.1. PROGRAMI

P.1.1. LTspice

LTspice je softver visokih performansi za simulaciju električnih mreža proizveden od proizvođača

poluvodiča Analog Devices, koji omogućava dizajn shema i pregled valnih oblika i odaziva mreže

na poticaje, a s svojim poboljšanjima i modelima komponenti olakšava simulacije analognih

krugova.

Program omogućava analizu strujnih krugova pomoću simulacija prijelaznih stanja, šuma,

izmjenične analize, istosmjerne analize i analize statičkih radnih točki.

Koristi se od mnogih inženjera u poljima za radio elektroniku, elektroenergetiku, audio elektroniku

i mnogim drugim.

P.1.2. KiCad

KiCad je program otvorenog koda (open source) koji služi za crtanje shema, dizajniranje tiskanih

pločica i izvoz potrebnih informacija poput popisa komponenti, Gerber datoteka i 3D pogleda na

tiskanu pločicu i njene komponente. Uz suradnju sa CERN-om KiCad je doveden u rang sa

plaćenim komercijalnim programima poput Altiuma i EAGLE-a.

Bitne funkcija KiCad-a su sloboda simbola u shemi i footprinta na pločici, što znači da za

potenciometar u shemi možemo reci da bude konektor ili nešto slično, Interactive router pomiče

vodove ili ih zaobilazi automatski.

P.1.3. ARTA Software

ARTA softver je zbirka programa za audio mjerenja i analizu u akustičkim i komunikacijskim

sustavima, koristi standardne i profesionalne zvučne kartice za računalo u svrhu prikupljanja i

generiranja audio signala.

ARTA softver sadrži tri programa:

ARTA.EXE - program za mjerenje impulsnog odziva, analizu spektra u stvarnom vremenu i

mjerenje frekvencijskog odziva.

STEPS.EXE - program za mjerenje frekvencijskog odziva sa sinusnom pobudom. Istodobno s

mjerenjem frekvencijskog odziva program procjenjuje razine harmonijskih izobličenja 2., 3., 4.,

5. i višeg reda.

LIMP.EXE - program za mjerenje impedancije zvučnika i procjenu parametara zvučnika.

P.2. SHEMA CJELOG PREDPOJAČALA

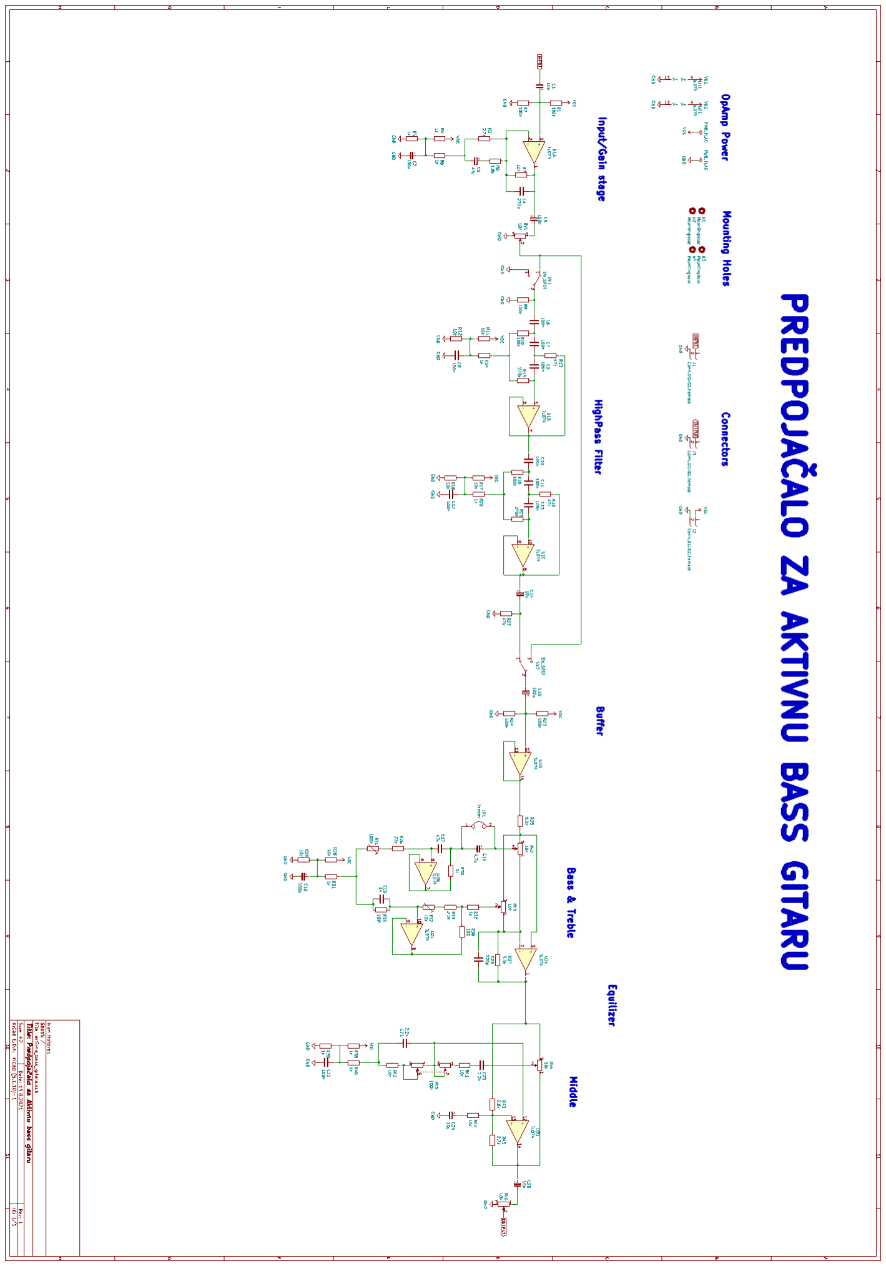
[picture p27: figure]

Slika.P.2.1 Shema predpojačala

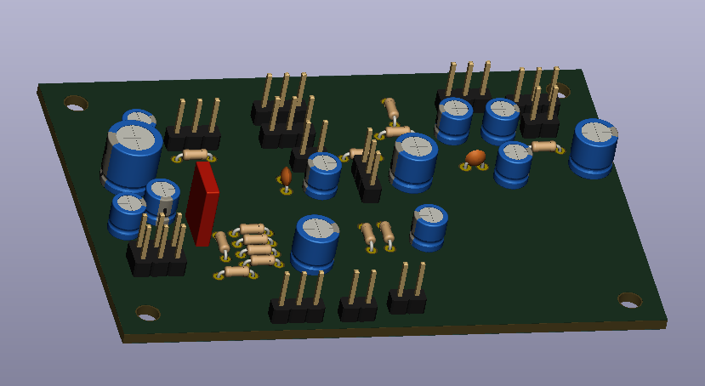
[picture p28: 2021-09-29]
Slike/Screenshot_2.png

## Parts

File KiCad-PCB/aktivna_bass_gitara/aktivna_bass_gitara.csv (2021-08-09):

Id | Designator | Package | Quantity | Designation | Supplier and ref
1 | SW1,SW2 | PinHeader_1x03_P2.54mm_Vertical | 2 | SW_SPDT
2 | H4,H3,H2,H1 | MountingHole_3.2mm_M3 | 4 | MountingHole
3 | R25 | R_Axial_DIN0204_L3.6mm_D1.6mm_P5.08mm_Horizontal | 1 | 3.3k
4 | R38,R6,R20,R31 | R_Axial_DIN0204_L3.6mm_D1.6mm_P5.08mm_Horizontal | 4 | 1k
5 | C25 | CP_Radial_D8.0mm_P3.50mm | 1 | 10u
6 | RV4,RV2,RV1,RV3,RV6 | PinHeader_1x03_P2.54mm_Vertical | 5 | 10k
7 | R43 | R_Axial_DIN0204_L3.6mm_D1.6mm_P5.08mm_Horizontal | 1 | 2.7k
8 | R23,R24,RT1 | R_Axial_DIN0204_L3.6mm_D1.6mm_P5.08mm_Horizontal | 3 | 100k
9 | R22 | R_Axial_DIN0204_L3.6mm_D1.6mm_P5.08mm_Horizontal | 1 | 47k
10 | C15,C2,C18 | CP_Radial_D6.3mm_P2.50mm | 3 | 100u
11 | U2,U1 | SOIC-14_3.9x8.7mm_P1.27mm | 2 | TL074
12 | R35 | R_0805_2012Metric_Pad1.20x1.40mm_HandSolder | 1 | 10M
13 | R44,R41,R42,R7,R11,R12,R17,R18,R28,R29 | R_0805_2012Metric_Pad1.20x1.40mm_HandSolder | 10 | 10k
14 | R36 | R_Axial_DIN0204_L3.6mm_D1.6mm_P5.08mm_Horizontal | 1 | 100
15 | R33 | R_Axial_DIN0204_L3.6mm_D1.6mm_P5.08mm_Horizontal | 1 | 2.2k
16 | R4,R5,R14,R30,R32,R39,R40 | R_0805_2012Metric_Pad1.20x1.40mm_HandSolder | 7 | 1k
17 | C9,C7,C10,C6,C11,C13 | C_0805_2012Metric_Pad1.18x1.45mm_HandSolder | 6 | 68n
18 | R13,R19 | R_0805_2012Metric_Pad1.20x1.40mm_HandSolder | 2 | 47k
19 | J1,J2,J3 | PinHeader_1x02_P2.54mm_Vertical | 3 | Conn_01x02_Female
20 | RV5 | PinHeader_2x03_P2.54mm_Vertical | 1 | 100k
21 | C21,C16,C23 | CP_Radial_D5.0mm_P2.00mm | 3 | 4.7u
22 | C1,C14,C24 | CP_Radial_D5.0mm_P2.00mm | 3 | 10u
23 | C3 | CP_Radial_D5.0mm_P2.00mm | 1 | 47u
24 | C4,C20 | C_0805_2012Metric_Pad1.18x1.45mm_HandSolder | 2 | 220p
25 | C5 | CP_Radial_D5.0mm_P2.00mm | 1 | 100u
26 | C8,C12,C22 | C_0805_2012Metric_Pad1.18x1.45mm_HandSolder | 3 | 100n
27 | C17 | C_0805_2012Metric_Pad1.18x1.45mm_HandSolder | 1 | 47n
28 | C19 | C_0805_2012Metric_Pad1.18x1.45mm_HandSolder | 1 | 1n
29 | JP1 | PinHeader_1x02_P2.54mm_Vertical | 1 | Jumper
30 | R1,R2,R9,R10,R16 | R_0805_2012Metric_Pad1.20x1.40mm_HandSolder | 5 | 100k
31 | R3,R45 | R_0805_2012Metric_Pad1.20x1.40mm_HandSolder | 2 | 2.7k
32 | R8 | R_0805_2012Metric_Pad1.20x1.40mm_HandSolder | 1 | 1.8k
33 | R15,R21 | R_0805_2012Metric_Pad1.20x1.40mm_HandSolder | 2 | 220k
34 | R26 | R_0805_2012Metric_Pad1.20x1.40mm_HandSolder | 1 | 22k
35 | R37 | R_0805_2012Metric_Pad1.20x1.40mm_HandSolder | 1 | 3.3k
36 | RT2 | R_Axial_DIN0204_L3.6mm_D1.6mm_P5.08mm_Horizontal | 1 | 10k

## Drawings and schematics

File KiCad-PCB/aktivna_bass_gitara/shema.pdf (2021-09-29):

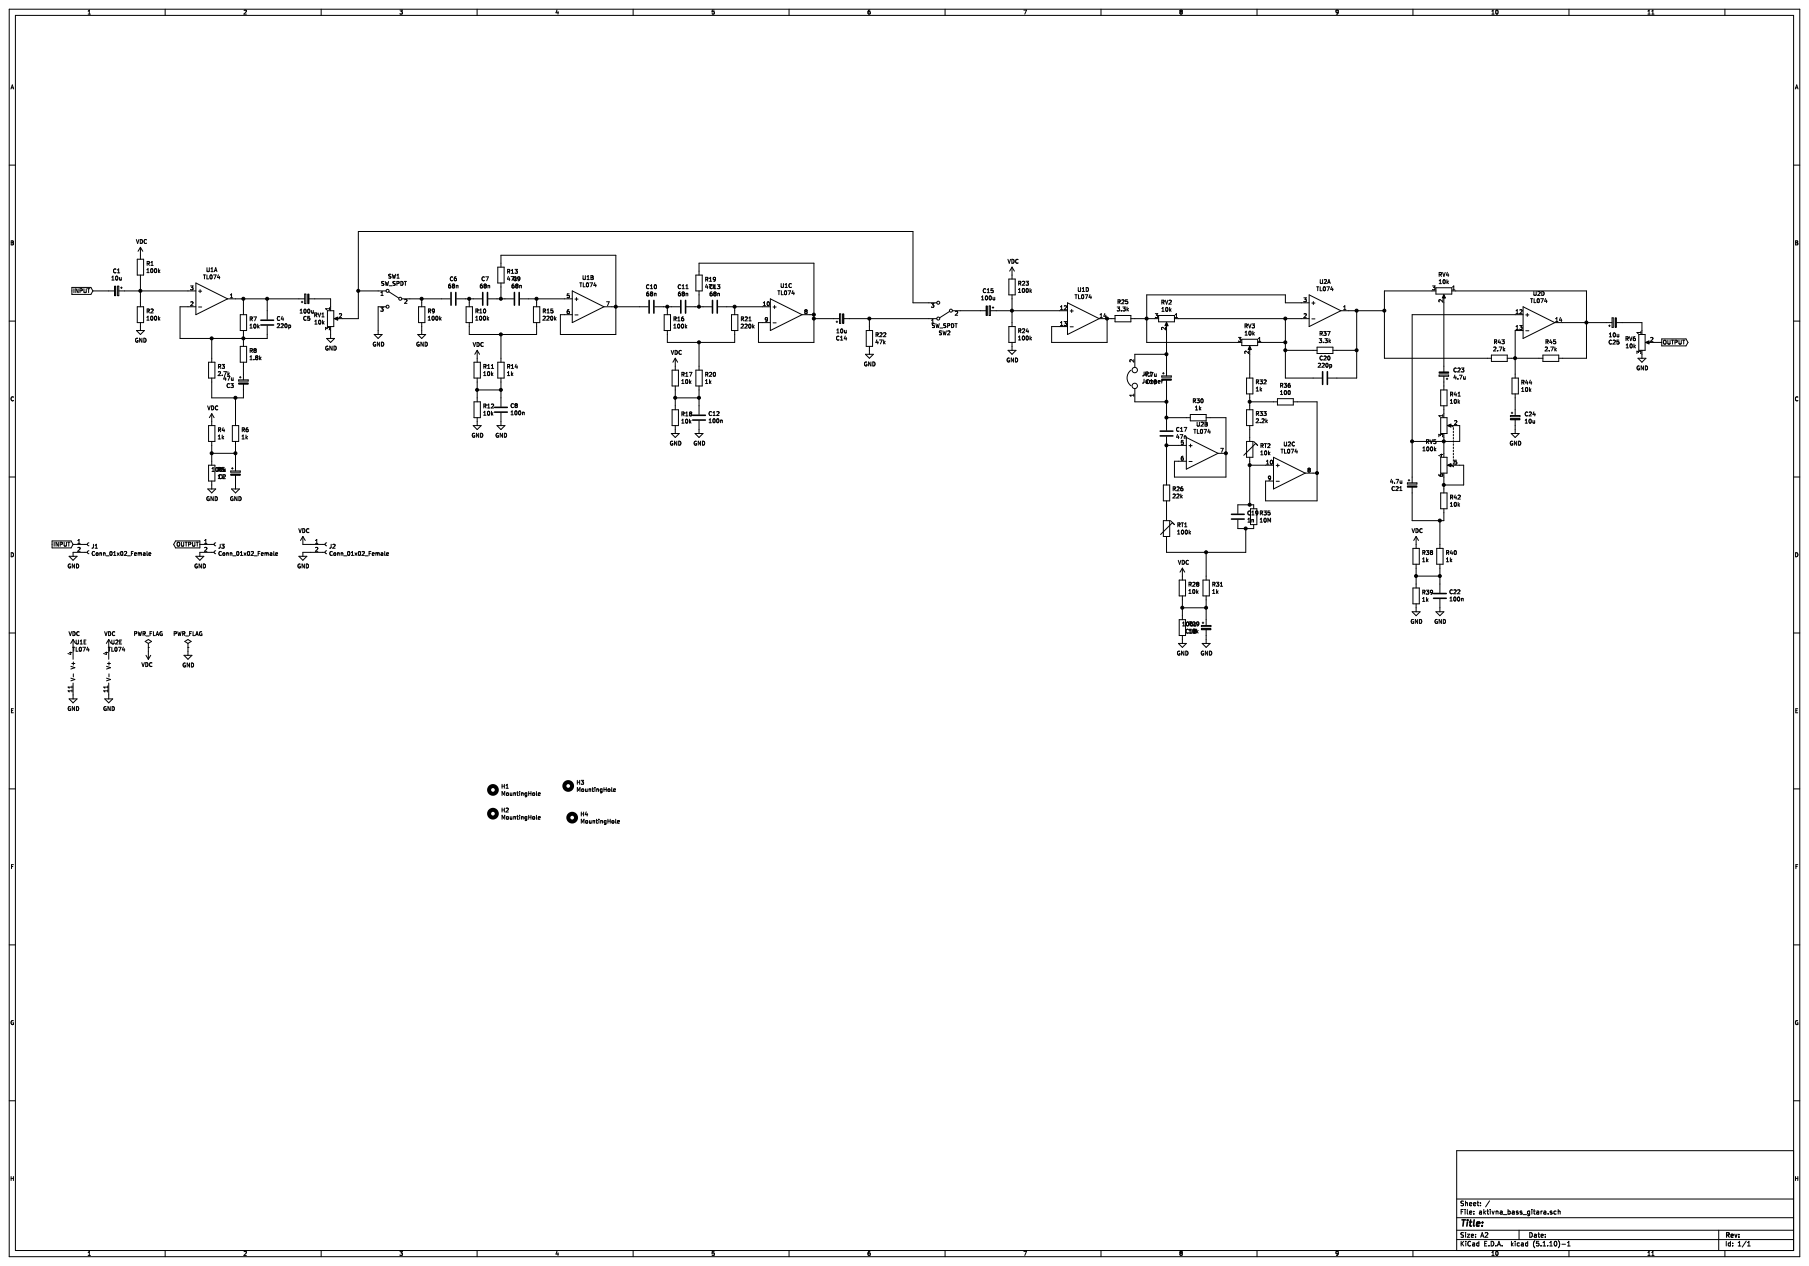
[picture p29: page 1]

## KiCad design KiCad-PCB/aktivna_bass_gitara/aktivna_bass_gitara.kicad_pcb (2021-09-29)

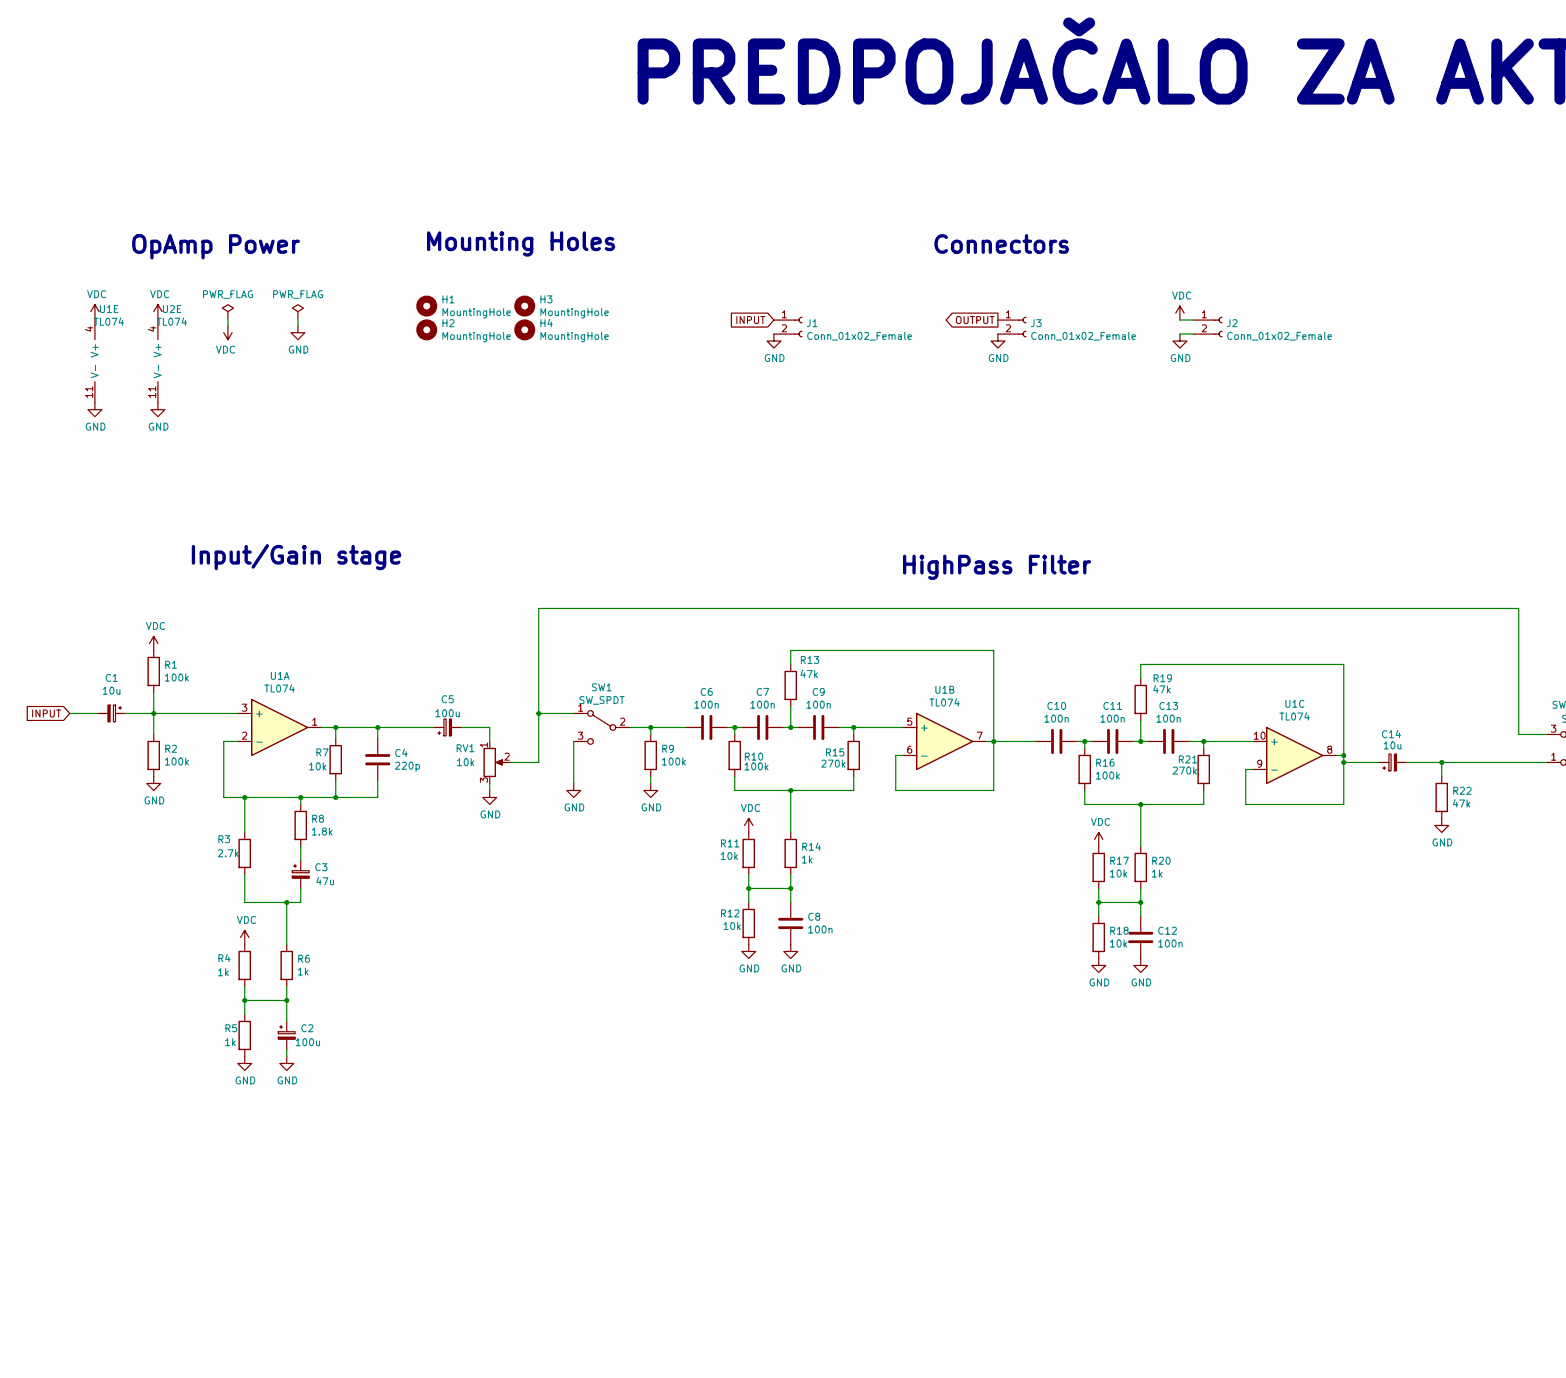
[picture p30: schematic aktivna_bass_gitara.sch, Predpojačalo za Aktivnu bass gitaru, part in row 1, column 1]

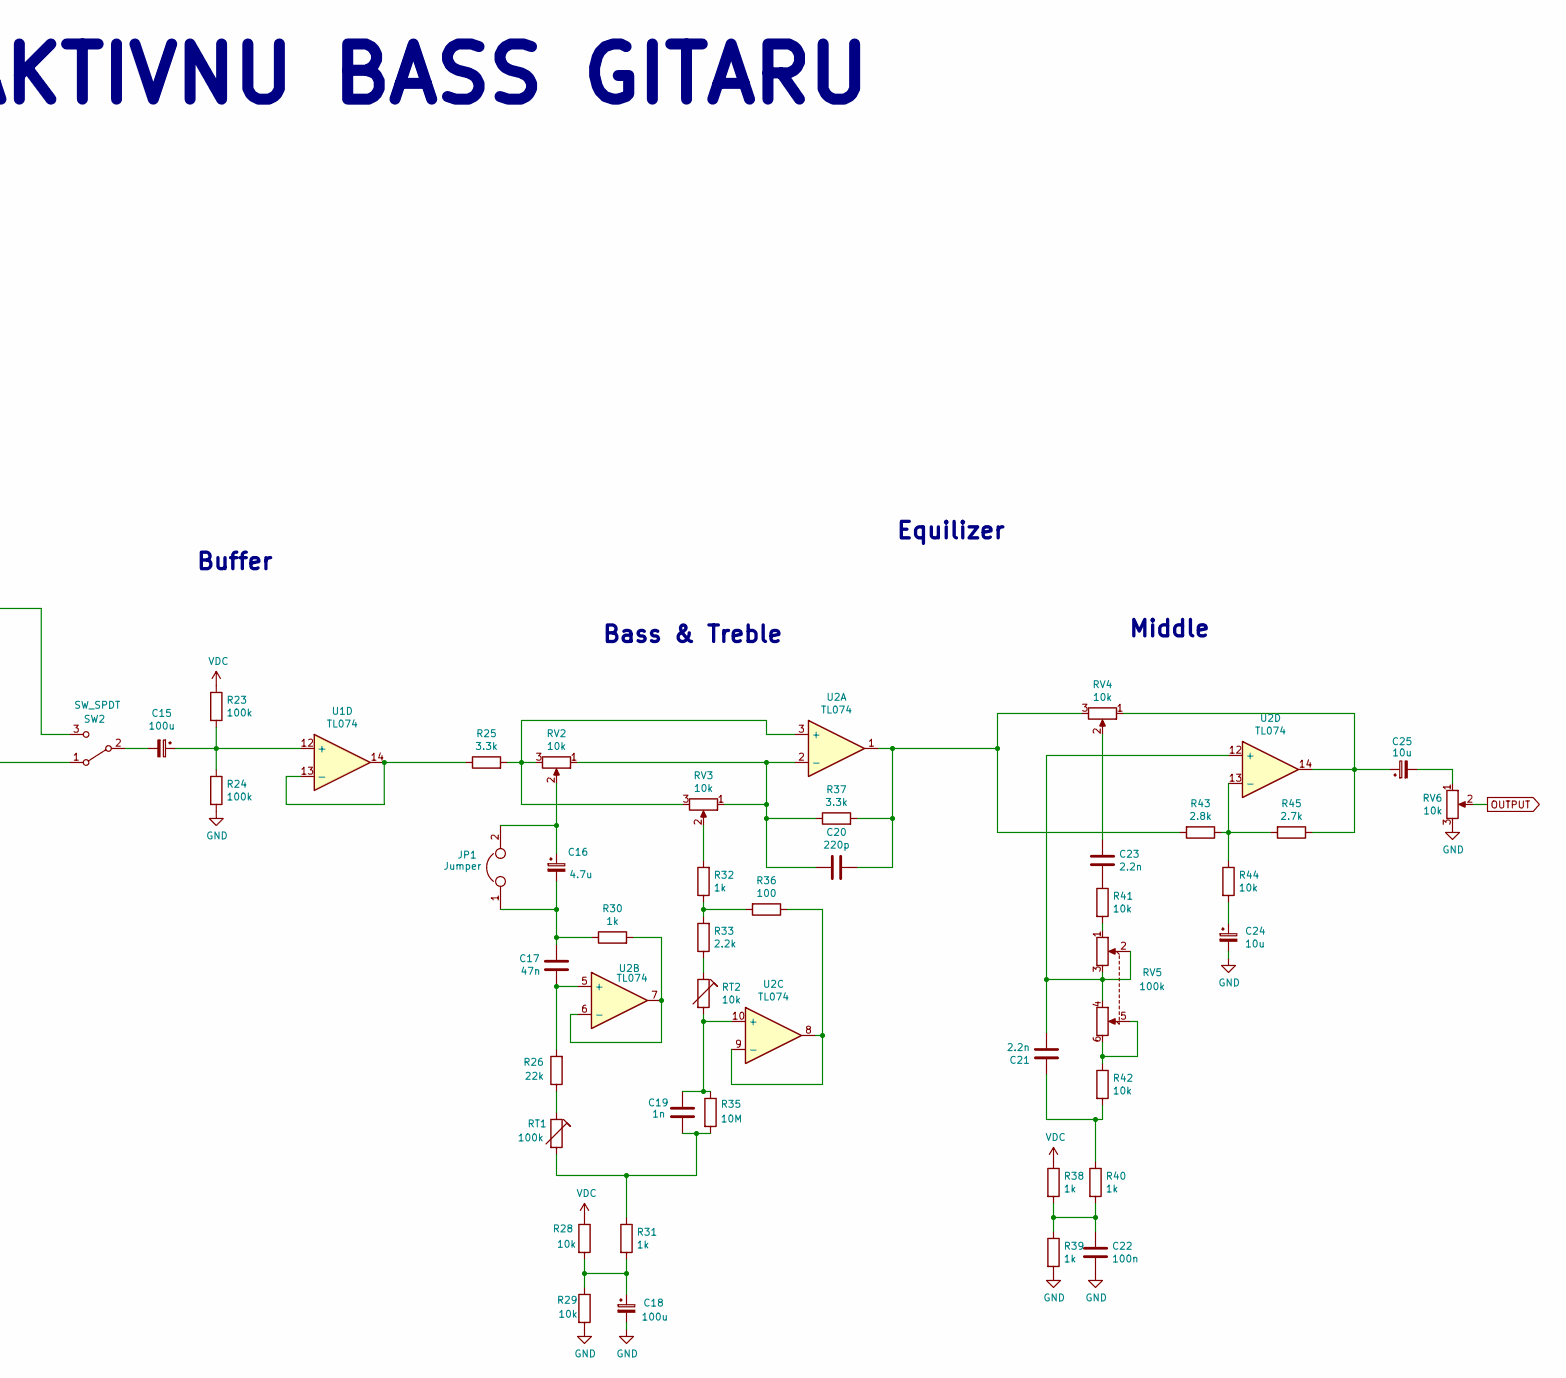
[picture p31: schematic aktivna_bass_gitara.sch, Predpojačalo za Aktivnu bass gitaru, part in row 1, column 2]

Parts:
C1, C14, C24: 10u; CP_Radial_D5.0mm_P2.00mm
C2, C15, C18: 100u; CP_Radial_D6.3mm_P2.50mm
C3: 47u; CP_Radial_D5.0mm_P2.00mm
C4, C20: 220p; C_Disc_D3.0mm_W1.6mm_P2.50mm
C5: 100u; CP_Radial_D5.0mm_P2.00mm
C6, C7, C8, C9, C10, C11, C12, C13, C22: 100n; C_0805_2012Metric_Pad1.18x1.45mm_HandSolder
C16: 4.7u; CP_Radial_D5.0mm_P2.00mm
C17: 47n; C_0805_2012Metric_Pad1.18x1.45mm_HandSolder
C19: 1n; C_Rect_L7.0mm_W2.0mm_P5.00mm
C21, C23: 2.2n; CP_Radial_D5.0mm_P2.00mm
C25: 10u; CP_Radial_D8.0mm_P3.50mm
H1, H2, H3, H4: MountingHole; MountingHole_3.2mm_M3
J1, J2, J3: Conn_01x02_Female; PinHeader_1x02_P2.54mm_Vertical
JP1: Jumper; PinHeader_1x02_P2.54mm_Vertical
R1, R2, R9, R10, R16: 100k; R_0805_2012Metric_Pad1.20x1.40mm_HandSolder
R3, R45: 2.7k; R_0805_2012Metric_Pad1.20x1.40mm_HandSolder
R4, R5, R14, R30, R32, R39, R40: 1k; R_0805_2012Metric_Pad1.20x1.40mm_HandSolder
R6, R20, R31, R38: 1k; R_Axial_DIN0204_L3.6mm_D1.6mm_P5.08mm_Horizontal
R7, R11, R12, R17, R18, R28, R29, R41, R42, R44: 10k; R_0805_2012Metric_Pad1.20x1.40mm_HandSolder
R8: 1.8k; R_0805_2012Metric_Pad1.20x1.40mm_HandSolder
R13, R19: 47k; R_0805_2012Metric_Pad1.20x1.40mm_HandSolder
R15, R21: 270k; R_0805_2012Metric_Pad1.20x1.40mm_HandSolder
R22: 47k; R_Axial_DIN0204_L3.6mm_D1.6mm_P5.08mm_Horizontal
R23, R24: 100k; R_Axial_DIN0204_L3.6mm_D1.6mm_P5.08mm_Horizontal
R25: 3.3k; R_Axial_DIN0204_L3.6mm_D1.6mm_P5.08mm_Horizontal
R26: 22k; R_0805_2012Metric_Pad1.20x1.40mm_HandSolder
R33: 2.2k; R_Axial_DIN0204_L3.6mm_D1.6mm_P5.08mm_Horizontal
R35: 10M; R_0805_2012Metric_Pad1.20x1.40mm_HandSolder
R36: 100; R_Axial_DIN0204_L3.6mm_D1.6mm_P5.08mm_Horizontal
R37: 3.3k; R_0805_2012Metric_Pad1.20x1.40mm_HandSolder
R43: 2.8k; R_Axial_DIN0204_L3.6mm_D1.6mm_P5.08mm_Horizontal
RT1: 100k; R_Axial_DIN0204_L3.6mm_D1.6mm_P5.08mm_Horizontal
RT2: 10k; R_Axial_DIN0204_L3.6mm_D1.6mm_P5.08mm_Horizontal
RV1, RV2, RV3, RV4, RV6: 10k; PinHeader_1x03_P2.54mm_Vertical
RV5: 100k; PinHeader_2x03_P2.54mm_Vertical
SW1, SW2: SW_SPDT; PinHeader_1x03_P2.54mm_Vertical
U1, U2: TL074; SOIC-14_3.9x8.7mm_P1.27mm

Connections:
GND: C2.2, C8.1, C12.1, C18.2, C22.1, C24.2, J1.2, J2.2, J3.2, R2.2, R5.2, R9.2, R12.2, R18.2, R22.2, R24.2, R29.2, R39.2, RV1.3, RV6.3, SW1.3 (C), U1.11 (V-), U2.11 (V-)
INPUT: C1.2, J1.1
unnamed: C1.1, R1.2, R2.1, U1.3 (+)
unnamed: C2.1, R4.2, R5.1, R6.2
unnamed: C3.1, R8.2
unnamed: C3.2, R3.2, R6.1
unnamed: C4.1, R3.1, R7.2, R8.1, U1.2 (-)
unnamed: C4.2, C5.1, R7.1, U1.1
unnamed: C5.2, RV1.1
unnamed: C6.1, C7.2, R10.1
unnamed: C6.2, R9.1, SW1.2 (B)
unnamed: C7.1, C9.2, R13.2
unnamed: C8.2, R11.2, R12.1, R14.2
unnamed: C9.1, R15.1, U1.5 (+)
unnamed: C10.1, C11.2, R16.1
unnamed: C10.2, R13.1, U1.6 (-), U1.7
unnamed: C11.1, C13.2, R19.2
unnamed: C12.2, R17.2, R18.1, R20.2
unnamed: C13.1, R21.1, U1.10 (+)
unnamed: C14.1, R19.1, U1.8, U1.9 (-)
unnamed: C14.2, R22.1, SW2.1 (A)
unnamed: C15.1, R23.2, R24.1, U1.12 (+)
unnamed: C15.2, SW2.2 (B)
unnamed: C16.1, JP1.2, RV2.2
unnamed: C16.2, C17.2, JP1.1, R30.1
unnamed: C17.1, R26.2, U2.5 (+)
unnamed: C18.1, R28.2, R29.1, R31.2
unnamed: C19.1, R35.1, RT2.2, U2.10 (+)
unnamed: C19.2, R31.1, R35.2, RT1.2
unnamed: C20.1, R37.2, R43.2, RV4.3, U2.1
unnamed: C20.2, R37.1, RV2.1, RV3.1, U2.2 (-)
unnamed: C21.1, RV5.2, RV5.3, RV5.4, U2.12 (+)
unnamed: C21.2, R40.1, R42.2
unnamed: C22.2, R38.2, R39.1, R40.2
unnamed: C23.1, R41.1
unnamed: C23.2, RV4.2
unnamed: C24.1, R44.2
unnamed: C25.1, R45.1, RV4.1, U2.14
unnamed: C25.2, RV6.1
unnamed: R10.2, R14.1, R15.2
unnamed: R16.2, R20.1, R21.2
unnamed: R25.1, U1.13 (-), U1.14
unnamed: R25.2, RV2.3, RV3.3, U2.3 (+)
unnamed: R26.1, RT1.1
unnamed: R30.2, U2.6 (-), U2.7
unnamed: R32.1, R33.2, R36.2
unnamed: R32.2, RV3.2
unnamed: R33.1, RT2.1
unnamed: R36.1, U2.8, U2.9 (-)
unnamed: R41.2, RV5.1
unnamed: R42.1, RV5.5, RV5.6
unnamed: R43.1, R44.1, R45.2, U2.13 (-)
unnamed: RV1.2, SW1.1 (A), SW2.3 (C)
OUTPUT: J3.1, RV6.2
VDC: J2.1, R1.1, R4.1, R11.1, R17.1, R23.1, R28.1, R38.1, U1.4 (V+), U2.4 (V+)

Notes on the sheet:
OpAmp Power
Mounting Holes
Connectors
Input/Gain stage
HighPass Filter
Buffer
Bass & Treble
Middle
Equilizer
PREDPOJAČALO ZA AKTIVNU BASS GITARU

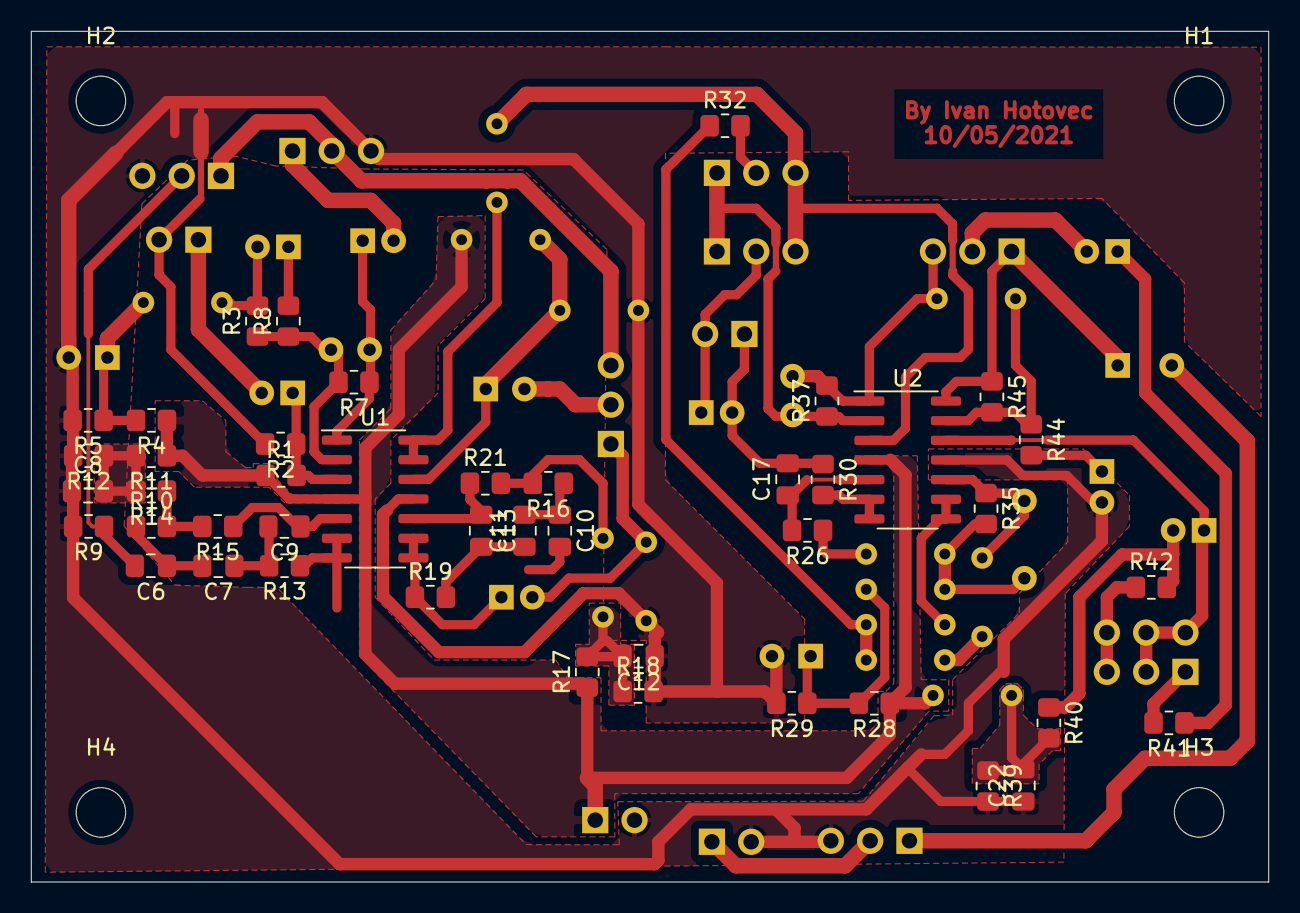
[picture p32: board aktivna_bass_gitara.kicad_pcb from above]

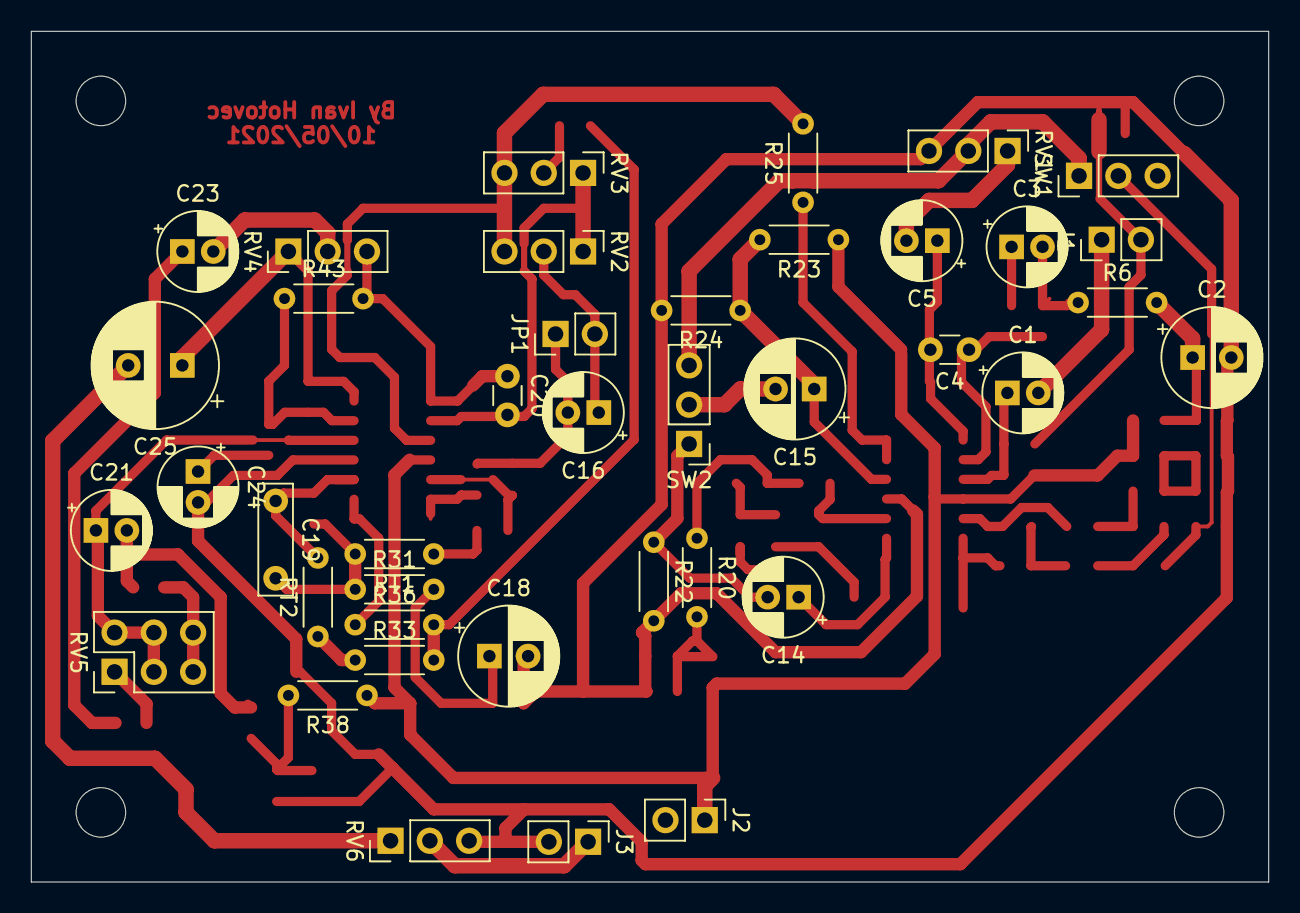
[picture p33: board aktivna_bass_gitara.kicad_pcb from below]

Board: 2 copper layers, 80.0 x 55.0 mm, 88 parts (40 on the bottom side), 55 nets.

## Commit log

2021-08-08 prvi
    prvi
    [aktivna_bass_gitara.kicad_pcb, aktivna_bass_gitara.sch]
2021-08-09 v2
    v2
    [aktivna_bass_gitara.csv, aktivna_bass_gitara.kicad_pcb, aktivna_bass_gitara.sch]
2021-08-09 v3
    v3
    [aktivna_bass_gitara.kicad_pcb, aktivna_bass_gitara.sch]
